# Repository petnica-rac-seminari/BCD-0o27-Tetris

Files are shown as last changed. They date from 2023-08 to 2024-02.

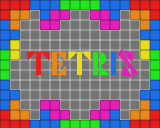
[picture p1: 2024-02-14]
firmware/framework/src/start_screen.png

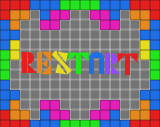
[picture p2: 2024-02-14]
firmware/framework/src/end_screen.png

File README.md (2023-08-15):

CHECK THE DOCUMENTATION FOLDER FOR INFORMATION ABOUT THE HARDWARE AND HOW TO BUILD IT.

The BalcCon Cyberdeck 0o27 (BCD-0o27) comes with a development framework that makes it easier to add functionality to the cyberdeck. This development guide introduces the framework, advises coding best practices and provides examples for adding functionality to the BCD.
Of course, you can ignore all of that and program the BCD either with esp-idf, rust, or any other framework that allows you to program ESP32 chips directly. However, this is not covered in this guideline.

# Introduction to the BCD-0o27 Framework
Before reading this chapter it is advisable to get  a local copy of the framework (see [[#Getting the Framework]]) and set up the development environment (see [[#Setting up the Development Toolchain]]). 
The framework consists of the following components:
- **Drivers**: The drivers for the hardware, namely the ST7735 display, the WS2812 LEDs  and the input buttons (aka controller) as well as the serial console. (Sometimes, drivers and libraries are not distinguished)
- **Libraries**: Libraries are provided for common tasks like opening a console on the serial port, establishing ssl connections or displaying graphical elements.
- **Modules**: Modules are programs that can be launched by the user. They can be simplest demo applications or complex programs.
- **Console Commands**: Console commands are programs that can be launched from the console. As modules, console commands can have any level of complexity. While usually they mainly interact with the serial console, they may - just as modules - access other hardware as well.

This document is currently being developed. For the time being, it is recommended to check the appendix to clone the repository. Then use the example firmware provided in the directory.

> [!info]
> You can connect to the badge using a serial console and a usb-c data cable. Make sure you use a terminal that understands ansi sequences. You can use the integrated serial monitor of platformio or espressif, but its highly recommended to use syncterm or minicom.

> [!warning]
> There currently is a bug in the serial console that will not give you a prompt when you connect using a serial terminal. In that case, leave the connection open and simply reset the badge by pushing the reset button - left button under the display.

# Appendix
## Getting the Framework
The framework is hosted as a git repository at https://gitlab.com/fschuetz/bcd-0o27.git. The repository makes heavy use of submodules, as many components for the BCD-0o27 are developed in parallel.
To create a local repository using git follow these steps:
```bash
git clone --recurse-submodules https://gitlab.com/fschuetz/bcd-0o27
```

## Setting up the Development Toolchain
In this chapter we will show how to set up the development environment consisting of git, espidf, Microsoft Visual Studio Code and Plattformio. If you are an experienced user, feel free to use the IDE of your choice.
### Installing GIT and cloning the repository
We will use git from the command line, as we have to deal with submodules, which are not well supported in the Visual Studio Code IDE.
If you have git already installed, you can skip this step.
1. Install git for your platform. Follow the guide at [Gitlab](https://docs.gitlab.com/ee/topics/git/how_to_install_git/)
2. Clone the repository: 
    ```bash
    git clone --recurse-submodules https://gitlab.com/fschuetz/bcd-0o27
    ```
Some tips on working with submodules, in case you run into a head detached situation: https://stackoverflow.com/questions/18770545/why-is-my-git-submodule-head-detached-from-master

### Install Microsoft Visual Studio Code (VSCode)
1. Install [VSCode](https://code.visualstudio.com/) for your operating system.
2. Open VSCode.

### Install C/C++ and PlatformIO Extensions
1. In VSCode: Open the "Extensions" side bar on the left side.
2. Search for the "C/C++" extension by Mircrosoft and install it.
3. Search for the PlatformIO IDE by PlatformIO and install it. See [PlatformIO IDE for VSCode](https://docs.platformio.org/en/latest/integration/ide/vscode.html#ide-vscode)
4. Once installation has finished, restart VSCode

### Build and Upload the Firmware 
In this chapter we will build the filesystem image and the firmware and upload both to the badge. If this works, then you can start developing your own firmware using the framework. For testing we highly recommend, taking the example in the directory `firmware/example` rather than the framework, as the example will give you running firmware that allows you to see something actually happening.
1. Start Microsoft Visual Studio and make sure you are in a new window, with no project loaded.
2. Select the alien head in the left bar (Platformio menu)
3. A left band appears. Select the blue button "Pick a folder"
4. From the cloned repository choose the `firmware/example` or the `firmware/framework` folder (as written above, its recommended to start with the example rather than the plain framework).
5. Click open.
6. Wait for platformio to configure itself. This is IMPORTANT: Between now and building the file there might raise popups in the bottom left corner asking you to install extensions or configurations. Usually you are asked to intall C++ specific extensions and CMake specific extensions. Confirm all of them. For CMake, if asked, you can "scan for kits". Scan for kits may also go away on itself, then everything is fine as well. 
7. If all went well so far you will recognise a blue ribbon / button on the bottom and some symbols like a home, a checkmark, roght pointing arrow etc.. If there is the message "Platformio: Loading tasks..." wait until it disapears. (this may take a long while). PlatformIO will automatically configure the project.
8. Open the file main.cpp in the "src" folder.
9. In the bottom task list (with the blue ribbon / button and the checkmark etc...), first choose the build environment by clicking on the symbol that looks like a folder and says "Switch Platformio Project Environment" if you hover over it. Usually it reads default right to the symbol. Choose `env:BCD-0o27-5KY` (or the `env:BCD-0o27-5KY-release` if you want to build for release rather than debug - if unsure make a debug build).
10. Now select the checkmark to build the project. This builds the project. Dependencies are pulled in automatically. In case Platformio does not pull in the Espressif 32 framework, follow the steps in the note below to install it manually.
11. If the project builds successfully, connect your badge to the computer using a usb-c cable (make sure it is actually a data cable and not just a charging cable)
12. Make sure the device is recognised. If the device is not recognised and a com port assigned, you might have to install a driver for the CH340 serial bridge. Follow the instructions from [Sparkfun](https://learn.sparkfun.com/tutorials/how-to-install-ch340-drivers/all#drivers-if-you-need-them)
13. Once the device is recognised, in VSCode we will build the file system image, upload it and then upload the code.
14. From the side bar choose the PlatformIO icon (alien head)
15. Select BCD-0o27 -> Plattform -> Build Filesystem Image
16. When finished, select BCD-0o27 -> Platform -> Upload Filesystem Image (BCD-0o27)
17. When finished, select the right pointing arrow ("Platformio: Upload") in the blue ribbon at the bottom. The project will be built and uploaded to the badge.
18. Either launch the serial console from the blue ribbon by selecting the plug icon ("Platformio: Serial Monitor") or use minicom (preferred). Note, that the Platformio Serial Monitor may display some strange characters or double print the prompt as it does not fully support the output mode. IMPORTANT: Due to a bug, the serial console only works for input if the connection was made at badge startup. If you do not see a prompt, leave the console on and restart the badge by pushing the power button (left between display and battery holder).
19. CRITICAL: Make sure, that you DO NOT have a serial monitor running when trying to flash the badge. This will lead to flash failure (for both, filesystem and firmware).

Note: The Espressif 32 framework should install automatically when building the project. If this is not the case, you can install it manually:
1. Open the Platformio sidebar (left side, alien head icon).
2. Select PIO Home -> Platforms
3. Click on the "Embedded" tab. Search for "Espressif 32" and click it.
4. Install the latest version. (At the time of writing this is version 5.1.0. While we plan to adapt the framework to newer versions, you might want to select this version if the newest version is not working due to breaking changes.)
5. Once the installation has completed confirm the success dialog.
### Helpful Resources
[Espressif 32 for Platformio](https://docs.platformio.org/en/latest/platforms/espressif32.html)

## Misc notes - ignore please
### Updating mirrors 
Go to lib directory of mirror
```
git fetch upstream 
git merge upstream/master
git push
```

### Updating submodules
```
git fetch
git pull
```

# Coding Style
```c++
ESP_LOGE(TAG_MODULE_NAME, "This is a rather long error message."
		"It should be spred on two lines");
```
If functions too long, spread on multiple lines. Two lines, indent second line by one tab and finish the line with closing bracket and ;. If more than two lines use one argument per line and close on a separate line as follows:
```c++
myfunction_with_many_arguments(
	argument 1,
	argument 2,
	argument 3

```

TO BE CONTINUED

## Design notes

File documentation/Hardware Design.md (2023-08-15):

Version: 0x00
Applies to: HW Rev. 0x00

This guide describes design considerations for the BCD-0o27. Note that not all of these were used in the actual design.

## Purpose of the document
This document describes the hardware design options and design decisions for
the BalcCon Cyberdeck BCD-0o27.

## General HW Design Considerations and Decisions
According to the [concept document](CONCEPT.md) the cyberdeck needs to support
the following functionality:

1. Some means of input to solve riddles / control programms stored on the badge
1. A display to display programm / riddle output
1. Storage to store programs and riddles on the badge
1. Some means to blink patterns on leds and some means to record blinking
    patterns from other badges
1. Run on battery power and alternatively be powered by USB. Optionally support
    charging of the battery over USB
1. Support wireless communication to connect to mutli user dungeon (mud)
1. Support a means to communicate with a computer using the badge to access the
    mud

### Core Module
The core modules ideally supports wireless communication WiFi and bluetooth out
of the box, offers a multitude of serial interfaces and has either built in 
flash storage or can easily be connected to external storage. Further, the core
module should be able to run code for passing through serial to WiFi for MUD
access as well as offer the mini games and riddle that run badge local. 
Considered options are:

1. Using an ESP32 as the core module.

    - ***Pro***: We know it well and it supports WiFi, Bluetooth and many
        serial communication protocols. Also the ESP32 offers many GPIO pins.
        The price for modules is low, sourcing is easy and there is a big 
        community for support.
    
    - ***Con***: ?

1. Using an STM32 as the core module.

    - ***Pro***: Low power CPU used in many projects.

    - ***Con***: Knowledge about the STM32 is small with the authors. Prices
        currently raise for this chip due to global shortage. Does not have 
        WiFi or bluetooth built in.

(***DECISION***) We will use the ESP32 as core module for the badge.

### Controls
The badge shall support a mode of direct input that allows navigating a menu
and playing little games / enter text or codes for applications running localy
on the badge. The options for input are:

1. Only push buttons. Due to space constraints, a full push button keyboard
    does not seem feasible. Therefore a layout of four push buttons to naviagte
    left / right / up / down makes sense. Further at least two push buttons,
    one for selecting an input and one for canceling / go back is needed. This
    layout would also allow for simple games such as pac man, snake or simple
    jump and runs.

    - ***Pro***: Requires only digital inputs, no analog to digital converter.
        The buttons can be arranged in a matrix which requires 5 digital input
        pins. Left / right / up / down can be all pressed at same time, which
        supports diagonal movement in games.
    
    - ***Con***: Limits controls in little games as movement if full or none.
        Pressing buttons for left / right / up / down can be a little fiddly in
        games. eft / right / up / down can be all pressed at same time, which
        needs to be checked if it makes sense (eg. up and down simultuously 
        often does not make sense.)

1. Similar to the configuration above, but instead of push buttons for left / 
    right / up / down use a digital mini joystick.

    - ***Pro***: More natural steering in games. Avoids the checks for 
        simultanious button presses as only one direction can be active at a
        time. Still requires only digital inputs and can be arranged in a 
        matrix (TODO - maybe even more optimized as simultanuous button presses
        can not happen).

    - ***Con***: Limits controls in games due to digital logic (full or none).
        Combinations that make sense might not be available as the joystick
        might not support eg. top + left combinations (TODO - check if there
        are digital versions that support this. Note: Also NES and old consoles
        did not support this, so it is possible to design around that.)

1. Have an analog mini joystick (potentially also including a button press if
    pushed) for movement in menus and games and add two (or potentially more)
    buttons for select and back.

    - ***Pro***: Natural movement in games using analog signals to capture
        intensity of the move. Only sensible inputs for navigation (no up and
        down simultaniously). 

    - ***Con***: Requires at least four analog pins hooked up to an analog to
        digital converter (ADC). ADC2 cannot be used on the ESP32 as we use
        WiFi. ADC1 can be used but might also be used for other functionality
        such as LDO and LED. Might require having a separate ADC circuit and
        using a serial protocol for input to save GPIOs on the ESP32.

(***TODO***) Choose option and derive requirements in the chapter below. 
Proposal is to go with the simplistic 8 button variant first and only maybe
later consider going to a more complex version. Simplicity allows us to use
directly 6 digital pins and reduces complexity of the circuit, cost and 
development time.

### Display output
TODO - describe different display options (size / technology)

### Balcon Badge Blinky Logic Circuit (B3LC)
The B3LC consists of two parts: A set of six photosensitive elements to measure
light and a set six light emitting diodes (LED) to emit light. We start with 
some considerations for the photosensitive elements.

The photosensitive elements need to capture the light of the LEDs of other
badges to decode the blinking patterns those have. There are some options on
the photosensitive elements to use:

1. Light dependent resistors (LDR) are resistors whose resistance drops with 
    the amount of light that falls on them. This allows to determine the 
    brightness of the light source. 

    - ***Pro***: Simplicity of the circuit, availability and low cost of parts.

    - ***Con***: Each LDR needs to connect to an anaolg pin which means either
        the LDRs exhaust all available PINs on the ESP32 (ADC1, as AD" canot be
        used when using WiFi) or the LDRs need to be hooked up using an ADC
        multiplexer (ADC-MUX) which increases design complexity (but on the 
        other hand allows us to use a more exact ADC than the one of the ESP).

        Stray light is an issue with the LDRs as it influences the read values.
        This must be designed around by either developing a robust decoding 
        protocol with coarse granularity and fault tolerance and / or design
        the BCD-0o27 with some casing elements to snug fit LED on LDR when two
        badges are combined. 

1. Using a digital red, green and blue color light sensor (like for example the
    ISL29125) allows to directly detect light and its colors and decode it in a
    digital format.

    - ***Pro*** Allows to use a bus to communicate with the sensor and directly
        use digital pins. There are sensors with infrared blocking filter which
        reduces the amount of error. Also, detecting rgb components of light 
        allows for using more complex blinking patterns and introducing better
        error correction.

    - ***Con*** Cost of parts. Sourcing of parts. Also depending on what bus the
        parts use to communicate with the ESP32 more or less pins are used. If
        the part uses I2C it needs to be ensured that 6 different addresses are
        available and no adress collisions with other parts (eg. maybe display)
        occure. Parts using I2S buses do not suffer from these conditions but
        use more pins for chip select.

The LEDs need to emit light in a pattern such that it can be captured by the 
photosensitive elements and decoded. For this the following options exist:

1. Use a single colour (potnetially different ones for each) LED that either is 
    off or on.

    - ***Pro***: Easy to source (also as SMD), low cost, low complexity. Can be
        directly connected to 6 digital output pins of the ESP32. Keeps the 
        circuit complexity low and does not need additional parts.

    - ***Con***: Does only allow simplistic light patterns. Also limits the
        complexity of patterns that can be recognised as codes can only use
        on / off state and complexity of patterns must be introduced by using
        longer codes (not necesserily a bad thing). Maybe some poor peoples PWM
        to have different brightness levels could be implemented in software to
        allow for interesting patterns (using interrupts for exact timing)?

1. Use single colour LEDs but steer them with pulse width modulation (PWM) to
    allow for different brightness.

    - ***Pro***: Allows for more complex protocols having multiple states 
        depending on LED brightness (limited by accuracy of decoding). More
        important, allows for more interesting light patterns (pulsating lights
        and so on). The ESP32 supports 16 pwm channels grouped in two 8 channel
        groups.

    - ***Con***: None pwm specific. (?)

1. Use rgb tri-color LED steered with pwm.

    - ***Pro***: Allows for very interesting LED effects and also allows to
        come up with a sophisticated light coding protocol.

    - ***Con***: Litle more expensive than single color leds, little increased
        power consumption. Needs either a bus to steer leds or 18 channels.
        This exhausts the 16 available pwm channels on the ESP32 and also its
        not sure if enough pins are available (TODO - revisit after deciding on
        other peripherals) to have eg. 16 pwm channels and 2 digital.

(***TODO***) Add more options (maybe) and decide on what option to implement
first. While RGB LED with RGB light sensor is most interesting, it is also the
most complex and could be reserved for future badges. Maybe go with simple LDR
and pwm controlled leds (single to start, then maybe RGB as for LDR only 
intensity, not colour matters).

### Variants
On the one hand, device cost will be crucial for the BCD-0o27. On the other the
plan is that the BCD-0o27 can be used for several years to come (even if there
might be new version, we strive for backwards compatability). This means some
more robust and thus more expensive design choices might be justified (for 
example the USB port could be protected against ESD or USB Power Delivery 2.0
could be implemented to ensure the USB port where the BCD-0o27 is connected can
source enough power instead of just not functioning porperly when connected).

Depending on the time available, we might offer multiple variants of the 
BCD-0o27 at different price points:

- IFL variant: The "I feel lucky" variant will be designed with minimum safety
  and cheapest possible parts.

- TRD variant: "The real deal" variant will implement bells and whistles and
  use quality, but more expensive chips for some functionality.

## Core Module Design

### Requirements
- (REQ-COR-001) Run programms and mini games
- (REQ-COR-002) Establish and maintain connection to mud
- (REQ-COR-003) Redirect input from serial line to mud
- (REQ-COR-004) Redirect output from mud to serial line
- ...

### MMU
At the heart of the BCD-0o27 an ESP32 will be used. The ESP32 is a highly 
integrated MCU that offers WiFi and Bluetooth functionality. At its core is a
Xtensa 32 bit microprocessor (single and dual core available). It has rom and
sram memory and supports various clocks and timers. The ESP32 offers advanced
interfaces to serials through 34 programmable general purpose input and output 
pins (GPIOs). It supports SPI, I2S, I2C and UART interfaces. It also offers low
power sleep modes which makes it a good choice to run on battery power. Further
it has  some security mechanisms such as secure boot, flash encryption and 
hardware  acceleration for some common algortihms. Last but not least the ESP32
features a mature development environment, comes with a large community that
supports developers and can be acquired cheaply. A complete overview about the
ESP32 can be found in the [ESP32 Series Datasheet](https://www.espressif.com/sites/default/files/documentation/esp32_datasheet_en.pdf)

(***NOTE***) The final decision on what ESP32 module to use exactly still needs
to be taken. Experiments will be conducted currently with a ESP32-WROOM-32E 
module and / or ESP32 DEVKIT (which includes USB power and serial interface). 
All the Pinouts given in this document refer to the ESP32-WROOM module. Refere 
to the [ESP32-WROOM-32E datasheet](https://www.espressif.com/sites/default/files/documentation/esp32-wroom-32e_esp32-wroom-32ue_datasheet_en.pdf)
for further information.

The WROOM32 has the following pinout (***WARNING*** physical pin numbers in the
image do not match the datasheet. We use the pin numbers from the datasheet.
Those start with pin 1 in in the top left corner and then increment by one
counterclockwise).

ESP32 WROOM32 pinout ESP32-WROOM32 pinout

### Power Management
The ESP32-WROOM needs the following pins to be connected for power:

| Pin | Name | Function |
| :---: | ---- | --- |
| 1 | GND  | Ground |
| 2 | 3V3  | 3.3V power supply (2.3V ∼ 3.6V, min 500mA) |
| 3 | EN | Module enable signal (active high) |

The power provided to the module must be within 2.3V and 3.6V. The EN pin can
be used to deactivate the module completely. However, the design of the 
BCD-0o27 does not foresee this. To preserve power, the ESP32 will be put into
deep sleep, but always be active. Therefore the EN pin will also be connected
to the 3.3V rail of the power supply. To ensure the power supply to the ESP32 
chip during power-up, it is advised to add an RC delay circuit at the EN pin.
The recommended setting for the RC delay circuit is usually R = 10kΩ and 
C = 1µF. 

(***DECISION***) The EN pin will be connected to a switch that is connected to
ground. This switch then operates as a reset switch to reset the ESP32.

(***DECISION***) An RC delay circuit with R = 10kΩ and C = 1µF will be added at
the EN pin.  

RC Delay Circuit

(***DECISION***) A 0.1µF and a 22µF capacitor in parallel will be added close 
to the 3V3 pin to filter ripples in the power supply rail.

### GPIO
The ESP32 features 34 GPIOs. Each GPIO has a mximum current draw rating of 
40mV. Due to the usage of the internal flash memory and the wireless some GPIOs
will not be available. The following GPIOs are reserved and canot be used:

| PIN  | GPIO | Reserved for |
| ---: | ---: | --- |
| 17 |  9 | Connected to integrated SPI flash |
| 18 | 10 | Connected to integrated SPI flash |
| 19 | 11 | Connected to integrated SPI flash |
| 20 |  6 | Connected to integrated SPI flash |
| 21 |  7 | Connected to integrated SPI flash |
| 22 |  8 | Connected to integrated SPI flash |

The remaining GPIOs listed in the table below are available for use in the 
BCD-0o27. However, the use of some requires to take special care as they fulfil
important functions:

| PIN  | GPIO | Type  | Limitation | Used for | 
| ---: | ---: | :---: | --- | --- |
| 13 | I / O | - | unused |
| 23 |  15  | I / O | Strapping pin, pwm at boot | SPI Bus Chip Select (Display) |
| 24 | 2  | I / O | Strapping pin | SPI Bus Data Command (Display) |
| 25 | 0  | I / O | Strapping pin | unused |
| 26 | 4  | I / O | - | SPI Bus Reset (Display) |
| 27 |  16  | I / O | - | unused |
| 28 |  17  | I / O | - | unused |
| 29 | 5  | I / O | Strapping pin, pwm at boot | unused |
| 30 |  18  | I / O | - | SPI Bus Clock (Display) |
| 31 |  19  | I / O | - | SPI Bus MISO (None) |
| 33 |  21  | I / O | - | Add on connector (I2C) Interface (SDA) |
| 34 | 3  | I / O | RX, high at boot | unused |
| 35 | 1  | I / O | TX, debug output at boot | unused |
| 36 |  22  | I / O | - | Add on connector (I2C) Interface (SCL) |
| 37 |  23  | I / O | - | SPI Bus MOSI (Display) |

***Strapping pins*** are sampled during the sample the voltage level during the
chip's system reset relase (power-on-reset, brown out reset, watchdog reset) as
strapping bits of "0" and "1". Those strapping bits determine the devices boot
mode, the operating volatage of VDD_SDIO and other system settings. See 
chapter [Boot Up](#boot-up).

### Boot Up
In order to boot the ESP32 up correctly the strapping pins must be set as
follows:

| Strapping PIN | Set | Effect | Mapping WR32E |
| --- | --- | --- | --- |
| MTDI |  0  | Set voltage to 3.3V | IO12 / pin 14 |
| GPIO0 | 1/0 | 1 on normal boot, 0 to flash new code | IO0  / pin 25 |
| GPIO2 | ?/0 | Must be 0 when flashing, don't care otherwise | IO2  / pin 24 |
| MTD0 |  0  | Debug output for boot (set 1 for development) | IO15 / pin 23 |
| GPIO5 |  1  | Rising edge sampling and output | IO5  / pin 29 |

Note that the strapping pins must be set during the system reset release (boot
phase) of the chip. The system reset release can be triggered by three 
conditions:
1. Startup of the chip, power on reset (EN pin goes high and system is powered)
2. RTC watchdog reset (TODO - excat conditions? Every wakeup?)
3. Brownout reset (voltage was too low or unstable to continue operation)

After system reset release (when the ESP32 enters normal operation) the pins 
are no longer relevant can be used as regular gpios.

It follows an explanation on the choice made above:
- MTDI: MUST always be set to 0, as the module only operates on 3.3V.
- GPIO0: In normal operation must be set to 1 to boot normally. When flashing
    new code on the chip must be set to 0.

    ***OPEN DECISION***: Shall we allow flashing new code after development?
    
        Pro: Could release new updates to the batch easily. Also we could either
        design it in a way where it is easily trigerable (using a switch) 
        encouraging tinkering with the badge or we could make it more difficult by
        bringing out a trace that can then be hooked up to a flasher that pulls the
        pin low making this more difficult, disencouraging fundamentally changing
        the badge.

        Con: Reflashing something completely new could render the badge to be
        used in ways not foreseen and make devleoping a interesting game 
        experience more difficult (more fault cases). In this case the HW 
        design must be such that it is really difficult to set the pin to low 
        at bootup.

        Decision: TODO

- GPIO2: When flashing (GPIO0 set to 0) must be set to 0. Otherwise does not
    matter. 

    ***OPEN DECISION***: Set to 0 during boot to be on the safe side when 
        reflashing or don't care?

        Pro: Setting to 0 at boot rules out one source of failure for flashing
        new code.

        Con: Depending on what is connected to the GPIO2 it could make the 
        circuit and software design more difficult to ensure that after boot
        the value needed by the connected chip or device is there.

        Decision: TODO

- MTD0: Sets whether debug output is given (on TXD0 / GPIO 1, which is pin 35
    on the ESP32-WROOM32E module). Can be set to 1 for development but is 
    disencouraged for use in release. Therefore must be set to 0 in release.

- GPIO5: If MTD0 is set to 0 does not matter. However, if MTD1 is set to 1 this
    pin defines the timing of the SDIO slave together with MTD0. TODO - decide
    what to use. Currently chosen 1 randomly.

### Entering Flash Mode
If we decide to allow for easy flashing, we will design two ways to flahs the
ESP32: Auto (if flasher supports it) and manual by button press. When using a
flasher (like [esptool.py](https://github.com/espressif/esptool) for example), 
some flashers will use DTR and RTS to signal that they want to flash. Thus 
those can drive transistors to switch the boot mode. Also, as some tools do not
support this a button to be manually pressed will be added. This button needs 
to be debounced using a capacitor.

## Blinky Interface
TODO

## Display
TODO

## Controls
The BCD-0o27 will feature a set of inputs:

For the joystick we will use a simple analogue 

### Circuit Design
We design the input of the buttons using a shift register. This allows to
record multiple buttons presses while only needing two pins on the ESP32
(serial in and clock).

### D-Pad Design
TODO

### Button Design
TODO

## Serial Interface
TODO

## (OPIONAL) Debug Interface
TODO

## Power Supply
(***WARNING***) Currently this chapter is very rough as components are not yet
decided. It must be adapted during the process. It is important to do this as
changing power requirements can rule out some options. We likely aim to high at
the moment, but this is preferable to too low.

The BCD-0o27 must be mainly powered by batteries to allow it to operate on its
own. When hooked up to an alternate power source this source shall be used to 
power the badge. Charging the battery is optional. 

### Requirements
The power supply design for the BCD-0o27 must fulfil the following 
requirements:
- (REQ-POW-001) Provide enough output current to power the BCD-0o27. For the
    exact amount check calculation in 
- (REQ-POW-002) Provide a 3.3V rail (min. 2.3V / max. 3.3V - may change 
    depending on additional parts used as they might have different power 
    requirements)
- (REQ-POW-003) Switch from battery power to external power source if attached
- (REQ-POW-004) Batteries shall be easy to source and replace
- (REQ-POW-005) Less hazardous battery technology shall be prefered
- (REQ-POW-006) Protect from reverse polarity

### Output current
The minimal amount of current the power supply must deliver is estimated by 
the sum of the current need of all components at typical full operation (ie.
for ESP32 this means wireless enabled and computing) and then add 10% as safety
margin.

NOTE: This current estimate is subject to change due to component selection
for the not yet selected components. Update accordingly.

    ESP32            500 mA (1)
    6xLED            360 mA (2)
    LCD               60 mA (3)
    3xShift reg.       3 mA (4)
    ----------------------- 
    Total            923 mA  

    (1) Typical operating current. Cummulative IO output current is 1200 mA.
    (2) If using WS
    (3) Measured ILI operated at 3.3V
    (4) To be confirmed

### Battery Options
The following options are considered for the BCD-0o27: 
- NiMH AA batteries
- Alkaline AA batteries
- LiFePo AA batteries
- LiFePo 18650 batteries
- Li-Ion 18650 batteries
- Li-Ion accu 3.7V (single cell)

The following table summarises properties of the different battery types. Note 
that depending on the manufacturer these values might differ slightly, however
this will not affect the design.

| Battery | Voltage nom/max/min | Capacity mAh | Max. discharge |
| --- | :---: | ---: | ---: |
| NiMH AA | 1.2 / 1.5 / 1.2 |  600–2750 | 3C |
| Alkaline | 1.5 / 1.5 / 1.2 | 1800–2850 | 0.5A - 0.75A |
| LiFePo AA | 3.2 / 3.65 / 2.0 | 600 | 3C (1800mA) |
| LiFePo 18650 | 3.2 / 3.65 / 2.0 | 1400 | 3C (4500mA) |
| Li-Ion 18650 | 3.6 / 4.2 / 2.5 | 2500 | 8C (20A) |
| LiPo pack 1S | 3.7 / 4.2 / 2.75 | 2000 | 1C (2000mA) | 

#### NiMH and Alkaline AA Batteries
NiMH and alkaline AA batteries have the big advantage that they can be found
anywhere and their price is low. Alkaline batteries however only provide a
continuous discharge current of 0.5A - 0.75A. While this should be enough for
regular operation, it does not provide many reserves and alkaline batteries in
general operate better at low discharge currents. 

Both, NiMH and alkaline AA batteries can directly supply enough voltage for 
the ESP32 without any voltage conversion. This reduces the complexity of the 
power supply design. The same should go for the OLED display, however, this 
must be verified (TODO). The charging circuit for rechargeable NiMH AA 
batteries is a little more complex, as two cells should be balanced to allow 
them both to fully charge. Also, if charging starts automatically when plugged
in to an alternate power supply, it might be that non rechargeable batteries 
are in use and the cahrging circuit canot detect this. Therefore the easiest 
design choice would be to not implement a chargin circuit and let the user 
change batteries when running low on power.

| Pro | Con |
| --- | --- |
| Battery safety | Charging circuit |
| Easy sourcing | Voltage below 3.3V (3V - 2.4V) |
| Low cost | Alkaline: low current < 750mA  |
| No need for buck / boost converter | |

TODO - charging circuit design (OPTIONAL) 

#### LiPo Pack 1S
A single cell LiPo battery pack has the advantage that a charging circuit is 
not too complex as no cell balancing is needed. The single cell LiPo battery
also is rather small and will only slightly increase badge volume and weight.
It offers decent capacity and enough continuous discharge current. 

Safety is a concern with LiPo batteries as over charging them may lead to fire
and over discharging them will permanently damage the battery. A wide range of 
ready made ICs for battery management exist and usually only require a couple 
capacitors and resistors asides the IC itself. Those battery management ICs are
needed for charging and discharging. They will take care of over charge and 
over discharge protection.

As a fully charged LiPo has a voltage of 4.2 V, this must be stepped down to
not damage the 3.3V logic components. The LiPo battery can be discharged to
2.5V although not discharging below 3V is recommended for battery longlifety.
Also, the residual usable charge between 2.5V and 3.3V is around 3% of the 
total usable charge. In order to provide power to the ESP32 and the other
components a 3.3V low dropout regulator (LDO) could be used. However, this 
would not allow us to use the full capacity range. Another option would be to
use a LDO that outputs 3V or even 2.5V, which would be enough for the ESP32. 
However, as with NiMH AA batteries this would need to be verified for the 
display and the other components. Alternatively a buck-boost converter could be
used to use the full range while providing a stable 3.3V power rail. The buck-
boost converter on the other hand generates an electromagnetic field that could
influence wireless quality if placed to closs to the ESP32. 

| Pro | Con |
| --- | --- |
| Can provide stable 3.3V power rail | Battery safety |
| Low cost | Needs battery management |
| High current (1C) | Sourcing need lead time |
| Reasonably simple charging circuit | |
| Low weight and volume | |

(***DECISION***) Even though many LiPo batteries come with a built in 
protection circuit, we will still design the protection circuit in the
BCD-0o27 to prevent bad things from happening if someone uses a battery
without a protection circuit.

#### Li-Ion 18650 battery
For the LiPo 18650 battery the same applies as for the Li-Ion pack 1S with the 
only difference that the battery uses more volume but provides roughly 25% more
charge and supports a higher average discharge current. 

| Pro | Con |
| --- | --- |
| Can provide stable 3.3V power rail | Battery safety |
| Low cost | Needs battery management |
| High current (8C) | Sourcing need lead time |
| Reasonably simple charging circuit | Larger volume |
| Low weight | |

For charging a single cell Li-Ion battery the 
[TP4056](https://download.bastelgarage.ch/Datasheet/TP4056_Datasheet.pdf) 
standalone linear Li-Ion battery charger with termal regulation in SOP-8 
package is frequently used. It charges the battery with a maximum of 1A 
directly from the USB port (5V supply) but can also be used with 6V solar 
panels. The chip features over voltage protection. It charges the battery to 
4.2V.

For protecting the the battery from over discharge, a 
[DW01](https://download.bastelgarage.ch/Datasheet/DW01A_Datasheet.pdf) in 
combination with a 8205 dual mosfet can be used.

(***DECISION***) If we decide to use multiple Li-Ion 18650 batteries in 
parallel to increase total capacity we will add fuses between the cells
to prevent fire hazard due to over discharge induced by a defective Li-Ion 
cell (short cell). The fuse disconnects the faulty cell.

#### LiFePo 18650
The main advantages of LiFePo over LiPo are that they are safer to use as they
will not burst in fire if overcharged and they also have a maximum voltage of
3.65V which is just at the top limit of the ESP32. Therefore no LDO or buck-
boost converter is needed.

TODO - check charge circuit and low power cut off necessity.

#### LiFePo AA
TODO

### USB Power
The BCD-0o27 will support powering from the USB-C port (see 
[AN1953 Introduction to USB Type-C](https://ww1.microchip.com/downloads/en/appnotes/00001953a.pdf))
for a good overview). Therefore the port on the BCD-0o27 is configured as an 
upstream facing port (UFP) and using pull down resistors on CC1 and CC2 to 
announce supported power requirements. We will only support 5V power modes. To
indicate voltage and max current, a Rp pull-down resistor must be used on both
CC1 and CC1. As the USB Type-C shall support charging at 1.5A@5V (at minimum) a
5.1kΩ±10% must be used. (Note: This results in a voltage divider when a cable
is attached. Depending on the resistor Ra used in the downstream facing port
The supported power mode is indicated. O

***Note***: The downstream facing port decides on the power capability it has
to offer. The minimum is 500mA / 900mA (USB2 standard). If the BCD-0o27 needs
more than 500mA we might run in problems when attached to a host that only
supplies 500mA. To avoid this we should implement the power delivery protocol
to indicate a minimal current requirement. However, we might also just ignore
this for simplicity and tell users. To be decided once total power requirements
are known.  

When plugged in the USB power shall be used to power the badge to safe battery
power. If we decide to use LiPo or LiFePo4 batteries, a charging circuit must
also be powered from the USB port. If we decide upon NiMH batteries charging
will not be supported as we want to avoid users using non-rechargeable 
batteries that are then charged inside the device. As chargers are cheap and
everyone has them this is an acceptable design choice that also reduces 
complexity and cost.

Last but not least, we might add ESD protection. ESD protection vill prevent
spikes due to ESD induced by humans plugging in the USB cable. Basically we
have two options:

1. [USBLC2-S2C6](https://datasheet.lcsc.com/lcsc/2106070106_UMW-Youtai-Semiconductor-Co---Ltd--USBLC6-2SC6_C2687116.pdf) 
   is designed for USB 2 applications. As we use a USB Type C plug
   with USB 2 protocoll, this is a feasible solution.

2. [TPD4E02B04](https://datasheet.lcsc.com/lcsc/1809131529_Texas-Instruments-TPD4E02B04DQAR_C106794.pdf) 
   is a 4-Channel ESD Protection Diode for USB Type-C and HDMI 2.0
   and is compatible to USB 3.1 GEN2, should we want to use those features.
   (unclear, but might even be needed if we want to use power delivery (TBC))

***Decision***: For the moment we will go with the USBLC2-S2C6 as we only use
   USB 2.0 features.

### Power Rails
The operation of the ESP32 requires a 3.3V power rail. Further, the BCD-0o27
will be designed around 3.3V as much as possible to avoid needing another
power rail and therefore limit the use of DC-DC converters (drives down cost
and reduces wasted power).
TODO - 5V?

#### 3.3V Power Rail
Multiple options, depending on the used power source exist. In order to output
3.3V either a low dropout regulator (ldo), a switching buck converter / 
buck-boost converter can be used. 

Low dropout regulators are easy to use, but they have worse efficiency than 
switching dc-dc converters. Also they limit battery choices as the voltage
of the battery that can be used must be higher than 3.3V+Vdo (droput voltage).
On the upside, ldos do not generate electromagnetic waves and thus do not 
interfere with WiFi, bluetooth and other sensitive components.

Switching dc-dc converters on the other side

### Reverse Polarity Proteciton
The battery could be inserted in the wrong way (not the USB) and therefore the 
power path from the battery must be protected agains reverse polarity. This can
be done with a P-channel mosfet with the gate clamped to ground. Using a mosfet
has the advantage over using a diode that it wastes less power. A diode 
wastes forward voltage times the current (Vf * I) power. A possible mosfet is 
[AO3401A](https://www.lcsc.com/product-detail/MOSFETs_BORN-AO3401A_C306862.html)
Note that the AO3401A requires a minimum of 2.5V for its operation. But this 
is fine as we can live with cutting of at that value independent of the
battery and boost converter we use. The maximum gate threshold voltage for the
AO3401A is -1.3V. The minimal battery voltage as stated above will be 2.5V. 
The parasitic body diode of the AO3401A has a forward voltage Vf_max of 1.0V.
Thus the gate-source voltage Vgs is at least 0V - (2.5V - 1V) = -1.5V which
is larger than the required -1.3V threshold voltage and thus the mosfet will
turn on. Once the mosfet has turned on, the resistance between drain and
source will drop to max 85mOhm.

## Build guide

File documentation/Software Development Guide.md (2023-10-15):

The BalCCon Cyberdeck 0o27 (BCD-0o27) comes with a development framework that makes it easier to add functionality to the cyberdeck. This development guide introduces the framework, advises coding best practices and provides examples for adding functionality to the BCD.
Of course, you can ignore all of that and program the BCD either with esp-idf, rust, or any other framework that allows you to program ESP32 chips directly. However, this is not covered in this guideline.

# Introduction to the BCD-0o27 Framework
Before reading this chapter it is advisable to get  a local copy of the framework (see [Getting the Framework](#Getting%20the%20Framework) and set up the development environment (see [Setting up the Development Toolchain](#Setting%20up%20the%20Development%20Toolchain)). 
The framework consists of the following components:
- **Drivers**: The drivers for the hardware, namely the ST7735 display, the WS2812 LEDs  and the input buttons (aka controller) as well as the serial console. (Sometimes, drivers and libraries are not distinguished)
- **Libraries / Components**: Libraries and components are provided for common tasks like opening a console on the serial port, establishing ssl connections or displaying graphical elements.
- **Modules**: Modules are programs that can be launched by the user. They can be simplest demo applications or complex programs.
- **Console Commands**: Console commands are programs that can be launched from the console. As modules, console commands can have any level of complexity. While usually they mainly interact with the serial console, they may - just as modules - access other hardware as well.

We distinguish two kinds of development work: Firmware development and framework development. Firmware development is using the framework to develop your own firmware to run on the hardware. Framework development modifying the framework itself to improve its performance or utility. Of course, the separation is not strict, as developing custom firmware might require modifications at the framework. For the sake of this guide we will differ between the two as clean cut as possible.

This document is currently being developed. For the time being, it is recommended to check the appendix to clone the repository. Then use the example firmware provided in the directory.

> [!info]
> You can connect to the badge using a serial console and a usb-c data cable. Make sure you use a terminal that understands ansi sequences. You can use the integrated serial monitor of platformio or espressif, but its highly recommended to use syncterm or minicom.

> [!bug]
> There currently is a bug in the serial console that will not give you a prompt when you connect using a serial terminal. In that case, leave the connection open and simply reset the badge by pushing the reset button - left button under the display.

# Firmware Development
This chapter will explain the code structure for developing firmware. Driver and library interfaces / usage is described in chapter [Drivers and Libraries](#Drivers%20and%20Libraries). To develop firmware using the provided framework, you will likely add custom modules and / or console commands. You can either start out with a clean slate by cloning the pure framework or you can start modifying the example firmware. Both can be found in the [gitlab repository](https://gitlab.com/fschuetz/bcd-0o27) Details on how to set up the repository and development environment can be found in the [Appendix](#Appendix).
If you are eager to get your hands dirty, then feel free to jump right into the example subsection of the according section about modules or commands. The example section will be an easy to follow mini tutorial. Just make sure to revisit the whole section, as the example will not cover everything and not explain why things are done.
## Modules
Modules are "self contained" pieces of code that are usually started through the menu (or execute on their own without user interaction). Modules should be structured as follows:
```
mod_<name of module>/
       |
       |--> include/
       |        |
       |        |--> mod_<name of module>.hpp
       |        |--> ...
       |
       |--> src/
       |     |
       |     |--> mod_<name of module>.cpp
       |     |--> ...
       |
       |--> CMakeLists.txt
       |--> KConfig
```
Modules must be stored in the `/modules` directory of the framework. They usually reside in their own git repository and are added to the `/modules` directory as a submodule. 
You could clone the framework from the original repository and then just add a directory for your module (and would then not need the CMakeLists.txt and the KConfig). However, this makes it hard to share your module with others. 
### Include Directory
The include directory must at least contain the header file for your module. It should be named the same as you top level directory with the file extension .hpp (as you are likely writing a c++ module. If not, you can do it, but you there are certain things to respect on how to use a c module within.). If your module needs other header files, this is also the right place to put them if they are needed outside your module. If not you can put them wherever you want.

### CMakeLists.txt
The `CMakeLists.txt` file is important for compilation. It will enable your module to be found. The file template looks as follows:
```
idf_component_register( SRC_DIRS     "./src"
						INCLUDE_DIRS "./include")
```
This will tell the build system to register your component (under the name of the top level directory) and to find the include files in the `include` directory and the source files in the `src` directory. 
If your module depends on other modules, then you need to make this explicit in the `CMakeLists.txt` file. For example, if your module uses GFX (which requires the module gfx for the library and ch405labs_gfx_drivers for the graphics driver) to draw graphics on the screen, you need to modify the `CMakeLists.txt` as follows:
```
idf_component_register( SRC_DIRS "./src"
						INCLUDE_DIRS "./include"
						REQUIRES ch405labs_gfx_drivers gfx)
```
### Using Framework Components (Drivers / Libraries)
The framework already provides you some special modules (called components) that make it easier for you to develop your own things. See chapter [Drivers and Libraries](#Drivers%20and%20Libraries) on how to include them into your project.
### Example
In this chapter we will write a little example module from scratch to demonstrate the workflow. All paths used in this example are relative to the home directory. Adapt them to whatever structures you choose. The example as it is presented can be directly applied on a linux or mac computer using a shell of your choice. On windows, some adjustments of eg. path names may be needed.
Further, this chapter assumes that you have set up the development toolchain properly. If you haven't done so, consult If you have not yet set up Visual Studio Code see [Setting up the Development Toolchain](#Setting%20up%20the%20Development%20Toolchain) to set up your development environment first!

#### Preparation
First, we clone the framework (if you haven't done so already). Make sure to also clone the submodules:
```bash
git clone --recurse-submodules https://gitlab.com/fschuetz/bcd-0o27.git
```
Now it is time to set up an empty git repository of your choice ([github](github.com), [gitlab](gitlab.com) or any other you like). Choose `mod_example` as the name for your module. You can initialise the module with a `README.md` if you want.
When done, clone it as a submodule into the `/modules` directory of the framework. Make sure to use the path to your git repository and make sure to clone it such that you can push your changes back to the repository.
```bash
cd bcd-0o27/firmware/framework/modules/
git submodule add -b main git@gitlab.com:BCD_0o27/modules/mod_example.git
```
To write a new module, it is easiest to copy the template module from the repository. The framework has the template module already present in the modules directory. Lets copy the relevant files into our own module and rename the `.cpp` and the `.hpp` file.
```bash
cp mod_template/CMakeLists.txt mod_example
cp mod_template/Kconfig mod_example
cp mod_template/README.md mod_example
cp mod_template/LICENSE mod_example
cp -r mod_template/include mod_example
cp -r mod_template/src mod_example
mv mod_example/include/mod_template.hpp mod_example/include/mod_example.hpp
mv mod_example/src/mod_template.cpp mod_example/src/mod_example.cpp
```
We now need to adapt the template to fit our module name. For this, open a new window (`File -> New Window`)in Visual Studio Code. Then open the directory `bcd-0o27/firmware/framework/`. Allow some time for platformio to properly initialise. 
Next we need to adapt some defines, variables and other elements to reflect the name of our module. We start with the `Kconfig` file. In Visual Studio Code open the `Kconfig` file in the folder `modules/Kconfig`. Then find and replace all `MOD_TEMPLATE` with `MOD_EXAMPLE`.  Also replace the name `Template`in the statement `menu "Console Command: Template"` with `Example`. Alternatively you can issue the following command from the command line in the `modules/mod_example` directory:
```bash
sed -i '' -e 's/MOD_TEMPLATE/MOD_EXAMPLE/g' Kconfig
sed -i '' -e 's/Template/Example/g' Kconfig
```
Feel free to adapt or remove the comments in the file (marked by `#` as the first character or the line).
Your Kconfig should now look something like this:
```Kconfig
menu "Module: Example"
	config TAG_MOD_EXAMPLE
	string "Tag for logging"
	default "MOD_EXAMPLE"
	help
		The tag to use for log messages.
	
	choice MOD_EXAMPLE_LOG_LEVEL
            bool "Log level for Example module"
            default MOD_EXAMPLE_LOG_EQUALS_DEFAULT

            config MOD_EXAMPLE_LOG_EQUALS_DEFAULT
                bool "Same as default"
            config MOD_EXAMPLE_LOG_LEVEL_NONE
                bool "No output"
            config MOD_EXAMPLE_LOG_LEVEL_ERROR
                bool "Error"
                depends on LOG_MAXIMUM_LEVEL >= 1
            config MOD_EXAMPLE_LOG_LEVEL_WARN
                bool "Warning"
                depends on LOG_MAXIMUM_LEVEL >= 2
            config MOD_EXAMPLE_LOG_LEVEL_INFO
                bool "Info"
                depends on LOG_MAXIMUM_LEVEL >= 3
		config MOD_EXAMPLE_LOG_LEVEL_DEBUG
                bool "Debug"
                depends on LOG_MAXIMUM_LEVEL >= 4
            config MOD_EXAMPLE_LOG_LEVEL_VERBOSE
                bool "Verbose"
                depends on LOG_MAXIMUM_LEVEL = 5
        endchoice

        config MOD_EXAMPLE_LOG_LEVEL
            int
            default LOG_DEFAULT_LEVEL if MOD_EXAMPLE_LOG_EQUALS_DEFAULT
            default 0 if MOD_EXAMPLE_LOG_LEVEL_NONE
            default 1 if MOD_EXAMPLE_LOG_LEVEL_ERROR
            default 2 if MOD_EXAMPLE_LOG_LEVEL_WARN
            default 3 if MOD_EXAMPLE_LOG_LEVEL_INFO
            default 4 if MOD_EXAMPLE_LOG_LEVEL_DEBUG
            default 5 if MOD_EXAMPLE_LOG_LEVEL_VERBOSE
    endmenu
```
Now replace all the `MOD_TEMPLATE` and `mod_template` in `include/mod_example.hpp`. You can do this in the editor or from the command line. Make sure to keep the case, it matters:
```bash
sed -i '' -e 's/mod_template/mod_example/g' include/mod_example.hpp
sed -i '' -e 's/MOD_TEMPLATE/MOD_EXAMPLE/g' include/mod_example.hpp
```
Now we are going to edit the mod_example include file to prepare it for writing our program. Open up the file in Visual Studio Code and do the following:
1. Adjust the information about your module and you the author in the first comment block
   - @author: Your name an email where ppl can reach you for questions.
   - @brief: A brief description of your module, eg. `Example file for BalCCon Cyberdeck modules.` 
   - @version: 0.1
   - @date: The current date
   - @copyright: `Copyright (c) <year>, <your name>, released under MIT license` (or choose another license that suits your purpose better).
   - Replace the longer paragraph describing the module with a suitable description, eg: `This module display a hello world text on the display and blinks the led's. The module will terminate, whenever the user presses a button.` 
2. You can either choose to keep both, `#pragma once`and the include guard `#ifndef BCD_MOD_EXAMPLE_HPP ...` or you can choose one of them. If you are unsure, just leave them untouched and use google to see why this is bad or why it is good and why one is better than the other - or not. Depending on the community.
3. We do currently not need to change our includes, as we intend to use all of those. Of course, if for example you future module does not need the controller, you can remove the controller include (and adapt the CMakeLists.txt to remove this dependency).
4. For the sake of trying to keep coding style consistent, make sure the comments after `#define MOD_EXAMPLE_FAIL ...` and `#define MOD_EXAMPLE_OK ...` start at character 81 (you need to move them one character back by adding a space in front).
5. In the comment of the Main function, adapt the description. Eg. to `This is the entry point into our module. It will run a loop that blinks the leds and aborts if a button is pressed long enough`.
This is all the adaption we need to do at the current stage. Your `mod_example.hpp` should now look similar to this:
```cpp
/**
 * @file mod_example.hpp
 * @author Florian Schütz (fschuetz@ieee.org)
 * @brief Example file for BalCCon Cyberdeck modules.
 * @version 1.0
 * @date 12.09.2023
 * @copyright Copyright (c) 2022, Florian Schuetz, released under MIT license
 *
 * This module display a hello world text on the display and blinks the led's.
 * The module will terminate, whenever the user presses a button.
 */ 

#pragma once
#ifndef BCD_MOD_EXAMPLE_HPP
#define BCD_MOD_EXAMPLE_HPP

#include <FreeRTOS/portmacro.h>
#include <stdlib.h>
#include "esp_log.h"
#include "st7735_bcd.hpp"
#include "gfx.hpp"
#include "ch405labs_esp_led.hpp"
#include "ch405labs_esp_debug.h"
#include "ch405labs_esp_wifi.hpp"
#include "ch405labs_esp_controller.hpp"

////////////////////////////////////////////////////////////////////////////////
// Menuconfig options
////////////////////////////////////////////////////////////////////////////////
#define TAG_MOD_EXAMPLE CONFIG_TAG_MOD_EXAMPLE

#if CONFIG_MOD_EXAMPLE_LOG_LEVEL == 0
#define MOD_EXAMPLE_LOG_LEVEL esp_log_level_t::ESP_LOG_NONE
#elif CONFIG_MOD_EXAMPLE_LOG_LEVEL == 1
#define MOD_EXAMPLE_LOG_LEVEL esp_log_level_t::ESP_LOG_ERROR
#elif CONFIG_MOD_EXAMPLE_LOG_LEVEL == 2
#define MOD_EXAMPLE_LOG_LEVEL esp_log_level_t::ESP_LOG_WARN
#elif CONFIG_MOD_EXAMPLE_LOG_LEVEL == 3
#define MOD_EXAMPLE_LOG_LEVEL esp_log_level_t::ESP_LOG_INFO
#elif CONFIG_MOD_EXAMPLE_LOG_LEVEL == 4
#define MOD_EXAMPLE_LOG_LEVEL esp_log_level_t::ESP_LOG_DEBUG
#elif CONFIG_MOD_EXAMPLE_LOG_LEVEL == 5
#define MOD_EXAMPLE_LOG_LEVEL esp_log_level_t::ESP_LOG_VERBOSE
#endif //CONFIG_MOD_EXAMPLE_LOG_LEVEL

////////////////////////////////////////////////////////////////////////////////
// Error handling
////////////////////////////////////////////////////////////////////////////////
typedef BaseType_t mod_example_err_t; 

#define MOD_EXAMPLE_FAIL -1                              /**< Generic failure */
#define MOD_EXAMPLE_OK 0x000                             /**< All good */

////////////////////////////////////////////////////////////////////////////////
// Macros
////////////////////////////////////////////////////////////////////////////////
// Put any macro here.

////////////////////////////////////////////////////////////////////////////////
// Namespaces
////////////////////////////////////////////////////////////////////////////////
// If you "use" namespaces, put them here.

////////////////////////////////////////////////////////////////////////////////
// Various Types
////////////////////////////////////////////////////////////////////////////////
// Put type definitions that don't fit above here.

// Any module should reside in its own namespace using the scheme
// bcd_mod_<name of your module>. Please adapt to the name of your module.
namespace bcd_mod_example {

////////////////////////////////////////////////////////////////////////////
// Main function
////////////////////////////////////////////////////////////////////////////
// While not mandatory, it is customary to call the entry point into your
// module `module_main()`. It must return an integer (0 on success) and
// has a void * parameter. The void pointer can point to more complex
// structures, which allow you to pass multiple parameters.
int module_main(void *param);

////////////////////////////////////////////////////////////////////////////
// Function prototypes, classes, ...
////////////////////////////////////////////////////////////////////////////
// Put your function prototypes or class definitions etc... here.

} // namespace bcd_mod_example
#endif // BCD_MOD_EXAMPLE_HPP
```
Next we prepare the `src/mod_example.cpp` file. Replace all the `mod_template`stings by `mod_example`. As done before, you can either do this in Visual Studio Code or on the command line:
```bash
sed -i '' -e 's/mod_template/mod_example/g' src/mod_example.cpp
```
Then copy the first comment block from you `include/mod_example.hpp` and replace the first comment block in `src/mod_example.cpp`. Your file should now look something like this:
```cpp
/**
 * @file mod_example.hpp
 * @author Florian Schütz (fschuetz@ieee.org)
 * @brief Example file for BalCCon Cyberdeck modules.
 * @version 1.0
 * @date 12.09.2023
 * @copyright Copyright (c) 2022, Florian Schuetz, released under MIT license
 *
 * This module display a hello world text on the display and blinks the led's.
 * The module will terminate, whenever the user presses a button.
 */

#include "../include/mod_example.hpp"

namespace bcd_mod_example {

////////////////////////////////////////////////////////////////////////////
// Main function
////////////////////////////////////////////////////////////////////////////
// While not mandatory, it is customary to call the entry point into your
// module `module_main()`. It must return an integer (0 on success) and
// has a void * parameter. The void pointer can point to more complex
// structures, which allow you to pass multiple parameters.
int module_main(void *param) {
  
#ifdef CONFIG_DEBUG_STACK
	UBaseType_t uxHighWaterMark;

	/* Inspect our own high water mark on entering the task. */
	uxHighWaterMark = uxTaskGetStackHighWaterMark( NULL );
	ESP_LOGD(CONFIG_TAG_STACK, "mod_example::module_main(): High watermark"
		" for stack at start is: %d", uxHighWaterMark);
#endif //CONFIG_DEBUG_STACK

#ifdef CONFIG_DEBUG_HEAP
	multi_heap_info_t heap_info;
	heap_caps_get_info(&heap_info, MALLOC_CAP_DEFAULT);
	ESP_LOGD(CONFIG_TAG_HEAP, "mod_example::module_main(): Heap state at"
								" start: \n"
								" Free blocks: %d\n"
								" Allocated blocks: %d\n"
								" Total blocks: %d\n"
								" Largest free block: %d\n"
								" Total free bystes: %d\n"
								" Total allocated bytes: %d\n"
								" Minimum free bytes: %d\n"
								, heap_info.free_blocks
								, heap_info.allocated_blocks
								, heap_info.total_blocks
								, heap_info.largest_free_block
								, heap_info.total_free_bytes
								, heap_info.total_allocated_bytes
								, heap_info.minimum_free_bytes);
#endif // CONFIG_DEBUG_HEAP

// <--- PLACE CODE BELOW HERE -->  

// <--- PLACE CODE ABOVE HERE -->

#ifdef CONFIG_DEBUG_STACK
/* Inspect our own high water mark before exiting the task. */
	uxHighWaterMark = uxTaskGetStackHighWaterMark( NULL );
	ESP_LOGD(CONFIG_TAG_STACK, "mod_example::module_main(): High watermark"
		" for stack at end is: %d", uxHighWaterMark);
#endif

	return 0;
}

} // namespace bcd_mod_example
```
#### Adding the Module to the Framework
While our module does not yet do anything, this is a good time to add it to the framework and check if everything compiles as intended. For our case, our module will be added such that it shows up in the main menu and can be executed by selecting it. 

> [!NOTE] Cleaning before compilation
> When adding a new module you need to clean the project before compilation in order to enable cmake to recognise the new module. This also applies, if you change the Kconfig file or the CMakeLists file.
> To clean the project either push the little trashcan icon in the bottom bar or choose the platformio menu on the left (alien head) and then in `Project Tasks`choose `Default->General->Clean all`.

First, we need to add our module header file in the includes section of the framework. For this, open the file `src/main.hpp` from the root directory of your framework. Find the line `// <----------------------------- Modules ------------------------------------->`and add the following after the last `#include` (but before the includes of the commands).
```cpp
#include "mod_example.hpp"
```
While you are at it, you can also remove the `#include "mod_template.hpp"` as we will not need it, now that we are developing a proper module.
>[!WARNING]
>Do not add your namespace to the namespaces or your module_main() will clash and lead to compilation errors.

Next open the `src/main.cpp`file. Search for the line that says `// <--- Set up objects etc... used throughout firmware below -->`. Here we will initialise our menu object. To do this add the following code:
```cpp
gfxmenu::MenuController<lcd_type, lcd_type::pixel_type> mc;
```

Now look for the line `// <--- Register modules below -->`. Below this line add the following code:
```cpp
mc.cursor->addEntry(mc.createActionItem("Hello BalCCon",
	bcd_mod_example::module_main, NULL));
```
This registers and action item as the first menu entry. An action item is an item that is executable. In our case, the menu entry is labeled `"Hello BalCCon"`, execution starts in the `module_main(...)` function of our module and we do not pass any arguments. For more information about how to build menus consult the chapter [GFXMenu](#GFXMenu). 
Las but not least, we need to display our menu and then run a main loop. For this to happen we first add the code to display the menu in the setup section. Look for the line `// <--- Put setup code and one time acitons below -->` and add the following code below:
```cpp
// Reset cursor and select first entry
mc.cursor->setToRoot();
mc.cursor->first();
mc.cursor->selectEntry();
lcd.clear(lcd.bounds());
mc.cursor->drawMenu(lcd, srect16(lcd.bounds()), lcd_color::alice_blue,
	lcd_color::dark_goldenrod);
```
As menus are always drawn from the element the cursor points at, we must set the cursor to the first element of the root menu (aka main menu). This is done with the first two statement. Then, we want the first element to be pre-selected (third statement). Next we clear the screen and then draw the menu.
Now its time to implement the main loop. In our case, the loop simply checks if button A or button B are pressed. If they are, the currently selected menu item is executed. Pressing the buttons up or down will select the next of previous menu item. In our case, as there is only one menu item, this will not do anything but it shows you how to do it when you add more modules. Look for the line that states `// <--- Implement your main loop below -->` and add the following code:
```cpp
for(;;) {
	// Query button and execute menuitem if button A or B is pressed.
	controller.capture();
	
	if(controller.getButtonState(BUTTON_DOWN)) {
		mc.cursor->deselectEntry();
		mc.cursor->next();
		mc.cursor->selectEntry();
		mc.cursor->drawMenu(lcd, srect16(lcd.bounds()),
		lcd_color::alice_blue, lcd_color::dark_goldenrod);
	} else if(controller.getButtonState(BUTTON_UP)) {
		mc.cursor->deselectEntry();
		mc.cursor->previous();
		mc.cursor->selectEntry();
		mc.cursor->drawMenu(lcd, srect16(lcd.bounds()),
		lcd_color::alice_blue, lcd_color::dark_goldenrod);
	}
	 
	if(controller.getButtonState(BUTTON_A)
		|| controller.getButtonState(BUTTON_B)) {
		
		const gfxmenu::Entry<lcd_type, lcd_type::pixel_type> *e =
		mc.cursor->getEntry();
		if(e != NULL && typeid(*e) == typeid(gfxmenu::ActionItem<lcd_type, 
			lcd_type::pixel_type>)) {
			int return_code = ((gfxmenu::ActionItem<lcd_type, 
				lcd_type::pixel_type> *)e)->execute();
			if(return_code < 0) {
				ESP_LOGE(TAG_STATE, "Could not execute menut item. Code %d",
					return_code);
			} else if (return_code > 0) {
				ESP_LOGW(TAG_STATE, "Menu execution returned with code %d.",
					return_code);
			};
			// Need to draw menu again, as execution could have used screen
			mc.cursor->drawMenu(lcd, srect16(lcd.bounds()),
				lcd_color::alice_blue, lcd_color::dark_goldenrod);
		}
	}
	// Delay to allow user to release buttons
	vTaskDelay(pdMS_TO_TICKS(250));
}
```
In our infinite loop, we first capture the pressed keys. Capturing keys records the state of the keys at the very moment this function is called. This is the reason why the last command in the loop is the `vTaskDelay()` command which puts the main task to sleep for 250 milliseconds. The sleep allows the user to release buttons before reading them again. If this command would not be here, the loop would record a pressed button many times and for example scroll through commands very fast. Make sure to read the chapter [Controller Driver](#Controller%20Driver) for more information.
After reading the button presses from the controller, we check if the down button was pressed. If the down button was pressed, we deselect the current menu item, move the cursor one menu item down and select it. We then need to redraw the menu to reflect the change on the display. Note that this does not have any effect in our current state, as we just have one menu item.
If the down button was not pressed, we check if the up button was pressed. If this is the case, we deselect the current entry, move the cursor one item up an in the menu and select it and then redraw the menu. If neither up nor down were pressed, we finally check if the A or B button was pressed. If this is the case, we check if the active menu item is an action item. This is done by checking the object type of the menu item. If the item is an action item, we execute it and check the return code. If the return code is 0, all is good. If it is smaller than 0, execution failed and we display an error to the console. If the return code is larger than 0 we display a warning that the module returned with a non zero code. After executing, we also need to redraw the menu, as the module may have changed what is displayed on the screen. Make sure to read the chapter [GFXMenu](#GFXMenu) for more information on how to build an navigate menus.
The code above successfully registers our module in a menu that is displayed on the cyberdeck and can be executed. Your can test this by compiling the module and flashing it to your cyberdeck. To do this, select Platformio in the left menu bar (the alien head). Then in the `Project Tasks` open the folder `BCD-0o27-5KY`. Wait for the project to self configure and then first clean the project by choosing `Genreal->Clean All` and then choose `General->Build` to build the project. If everything compiles fine, attach your cyberdeck to your computer using a USB-C cable and choose `General->Upload`. This flashes the firmware to your cyberdeck. Before doing this, make sure you do not have any serial console open that is connected to your cyberdeck. Otherwise flashing will fail.  
When you move up and down in the menu or execute the module you will see a short flicker, as neither the module does anything yet nor are there other menu items to scroll through.
If all of this is working, move on to the next chapter, where we finally implement the functionality of our module.
#### Implementing the Module - Part 1: Hello BalCCon
>[!INFO] Relative line numbers
>For the rest of this tutorial we are going to reference to line numbers relative to anchor points, because if you used longer descriptions in the preparation chapter, your line numbers culd differ. To enable relative line numbers in Visual Studio Code you can go to `Settings->Settings`. Search for "line numbers" and choose `relative`. You can jump to a specific line number pressing `CTRL+G`. 
>Alternatively you can just calculate the relative line numbers in your head and stick with the default.

For our module, we want to display the message "Hello BalCCon" in the middle of the screen and display the BalCCon logo as a background image. We also want to overlay some lines as an animation and blink the leds.
Lets start with the easy part, displaying the text all centred. Open `/modules/mod_example/include/mod_example.hpp` (relative to your framework root). From now on, we will no longer provide the full path in this chapter. All paths will be relative to the module root (`/modules/mod_example`). Search for the line `// <--- PLACE CODE BELOW HERE -->`. Then start by writing the following code below:
```cpp
#ifdef CONFIG_DISPLAY_SUPPORT

// First check if a display is supported
//
// Our module will require a display and will return an error if a display
// is not supported.
if(!bcd_sys.displaySupport()) {
	ESP_LOGE(TAG_MOD_EXAMPLE, "This module requires a working display.");
	return MOD_EXAMPLE_FAIL;
}

// Get refferences to display and font
lcd_type &lcd = bcd_sys.getDisplay();
const gfx::font& font = bcd_default_font_FON;

// Prepare the text and measure its dimensions.
const char* hello_balccon_txt = "Hello BalCCon";
gfx::srect16 hello_balccon_txt_rect =
	font.measure_text((gfx::ssize16)lcd.dimensions(),hello_balccon_txt).bounds();

//Clear the display and draw the text in the center.
lcd.clear(lcd.bounds());
gfx::draw::text(lcd,
	hello_balccon_txt_rect.center((gfx::srect16)lcd.bounds()),
	hello_balccon_txt,
	font,
	gfx::color<typename lcd_type::pixel_type>::chartreuse);

// Delay for 5 seconds
vTaskDelay(pdMS_TO_TICKS(5000));

#else //CONFIG_DISPLAY_SUPPORT

ESP_LOGE(TAG_MOD_EXAMPLE, "This module requires display support.");
return MOD_EXAMPLE_FAIL;

#endif //CONFIG_DISPLAY_SUPPORT
```
For referencing line numbers, the first line stating `#ifdef CONFIG_DISPLAY_SUPPORT`is referenced to as line number 1.
In this code we make some fundamental decisions about our module. The most important one is, that our module should only run on a cyberdeck which has a working display. At the time of writing, all cyberdecks have a display, but in the future, maybe there will be some low power cyberdeck variants without. In the configuration of the firmware display support can be deactivated for cyberdecks without displays (see [Cyberdeck Configuration](#Cyberdeck%20Configuration) for more information). If the configuration is set to no display, then the definition `CONFIG_DISPLAY_SUPPORT` is not present. This allows us to ensure code that uses the display is only compiled if the hardware we compile for actually supports a display. If not, the code size will be significantly smaller. Therefore, all our code that uses display functionality should go in between `#ifdef CONFIG_DISPLAY_SUPPORT ... #endif` preprocessor statements.
Unfortunately, there is also a second case we need to check. Even if a display is supported its initialisation may have failed during startup. We can test for this querying `bcd_sys.displaySupport()`. If the display works as expected, this function call will return true. 
As we made the decision that our module will only run if a display is supported and functional, we display and error in case a display is not supported (in the `#else` case of the preprocessor check) or the display is not function (line 7-10) and then return MOD_EXAMPLE_FAIL as an indicator for failure.
Once we established that we have a working display, on line 13 we get a reference to the display. We will need to pass the display as a parameter to the drawing functions we use. A reference in c++ stores the address of the variable it references. It can be seen as a non-NULL pointer. Syntactically it can be used like regular variables or objects and does not require dereferencing. If you want to know more about c++ references then [Microsoft - References in C++](https://learn.microsoft.com/en-us/cpp/cpp/references-cpp?view=msvc-170) is a good starting point.
To draw text, we also need a font. The BCD-0o27 comes with a default font. For ease of use we get a reference to this default font. On line 17 we define our text and then on line 18 measure it. This is necessary as when we draw text on the display, we always define a rectangle where to draw to. This can be all of the display, or any part of it. If the text is longer than this rectangle (and the rectangle is high enough to display more lines), the text is automatically wrapped. In our case, we want to make sure to draw to a rectangle just big enough to hold all of the text on one line. The function `font.measure_text(...)`does exactly that. Note, that this function on the one hand will also give you the correct size, in case your text includes line breaks (`\n`) and will also take into account as a parameter the maximum area for your layout (which in our case is the size of the display). If you want to know more about fonts, consult [honey the codewitch gfx - Fonts](https://honeythecodewitch.com/gfx/wiki/fonts.md).
Finally its time to draw on the display. We first need to clear the display to remove anything that is currently displayed. This is achieved with the function `lcd.clear(...)`. This function takes a rectangle to clear as a parameter. We want to clear the full screen and therefore pass the boundaries of the display as a parameter. Next we draw our text on the screen using the `gfx::draw::text(...)`function. As a first parameter we need to pass a reference to the source to draw to, which in our case here is the lcd. Next we need to define the rectangle to draw into. This rectangle is the size of the text offset in such a way that its center is at the center of the display. This can be achieved using the `.center(...)` function on the rectangle we measured before. This function takes the parent rectangle as a parameter, which in our case is the boundaries of the lcd. The next argument is the actual text to display, the font to use for displaying it and the color in which the text should be displayed. To learn more about colors refer to [honey the codewitch gfx - Pixels / Colors](https://honeythecodewitch.com/gfx/wiki/pixels.md#1.3). 
After having drawn the text on the display, we simply wait for 5 seconds, until our module terminates successfully.
Go ahead and compile and upload the framework to your cyberdeck to test you code. To do so, in the left menu choose platformio (the alien head) and then choose `General->Build`. Wait for the build to complete and then choose `General->Upload` with your cyberdeck connected to usb and switched on. Wait for the deck to reboot and you can now see the menu entry for your module on the deck and start it.
#### Implementing the Module - Part 2: LED blinking
TODO
#### Implementing the Module - Part 3: Displaying an Image
TODO
#### Implementing the Module - Part 4: Drawing Lines
TODO
#### Compiling the Release Version
TODO

> [!NOTE] Using submodules in your module
> A note about using submodules in you module: In case your submodule has other submodules, you also need to intitialise those using the `git submodule update --init` command in the directory of your module.

## Console Commands

## Cyberdeck Configuration
### Main Stack Size
TODO - explain stack of main task
The main task stack size depends heavily on how many modules and commands you use in your custom firmware and how much memory in the main task they require (some modules and commands may spawn own threads with their own stack). If you prepare a firmware, make sure to set the `CONFIG_ESP_MAIN_TASK_STACK_SIZE` in `menuconfig` accordingly. Also, it is recommended to add the appropriate stack size to the `sdkconfig.defaults`. 

> [!warning]
> Setting the value in `sdkconfig.defaults` does not overwrite existing configurations. It will rather take effect, if there is no existing configuration. So if you make that change during development, you need to set your `menuconfig` option anyways.
### Partition Table
Set the partition table in menuconfig. Set `custom_partition_table` to `partiontions.csv`. Set `Offset of partition table` to `0x8000`. 

> [!info]
> When using verbose logging or higher for the bootloader, it might be necessary to move the partition table to 0x10000 to make enough space for the bootloader.

## Preparing Firmware for Flashing / Delivery
Once firmware is final, potentially many devices need to be flashed. It is cumbersome to do this through the development environment. It is recommended to prepare the firmware as a binary package ready for flashing. To do this with platformio, first create a release profile if you haven't done so yet:
```

```
Next build the firmware in the development environment, just to make sure everything is fine. After all is set up correctly in the platformio core cli the following command will allow us to identify the needed parameters to build the project:
```bash
pio run -v -t upload
``` 
Depending on your setup, you might need to get the idf framework first by issuing `get_idf`. Also make sure you have a cyberdeck attached as the flash command should be able to execute.

The project is now being built giving verbose output. Towards the end, there will be the flash command with all parameters. The output may look something like this:
```bash
"/Users/fschuetz/.platformio/penv/bin/python" "/Users/fschuetz/.platformio/packages/tool-esptoolpy/esptool.py" --chip esp32s3 --port "/dev/cu.usbserial-1430" --baud 460800 --before default_reset --after hard_reset write_flash -z --flash_mode dio --flash_freq 80m --flash_size 16MB 0x0 /Users/fschuetz/Development/balccon_badge_workbench/checked_out_branches/firmware-design/balccon-badge/firmware/BCD-0o26_framework/.pio/build/BCD-0o26-5KY/bootloader.bin 0x8000 /Users/fschuetz/Development/balccon_badge_workbench/checked_out_branches/firmware-design/balccon-badge/firmware/BCD-0o26_framework/.pio/build/BCD-0o26-5KY/partitions.bin 0x10000 .pio/build/BCD-0o26-5KY/firmware.bin
```

### Some things to consider
TODO - Full clean wipes menuconfig. Add rtti and adapt main task stack size.
# Drivers and Libraries
# Framework Development
## Drivers
TODO
### Controller Driver
TODO
## Libraries 
TODO
### HTCW GFX
TODO
Display routines are provided by the htcw gfx library as templates. This means we need to provide the type of our drawing target (usually the display or a bitmap that we later display) as a parameter. Due to the nature of templates in c++ this means, we want to implement our routines that use gfx also as templates to enable them being used with any drawing target. To learn more about how gfx works please refer to chapter [HTCW GFX](#HTCW%20GFX). If you would like to better understand, why c++ templates need their implementation in the header (and how you could do it differently) this question / answer  [about c++ template implementation on Stackoverflow](https://stackoverflow.com/questions/495021/why-can-templates-only-be-implemented-in-the-header-file) can point you in the right direction.
### GFXMenu
TODO
## Components
TODO

# Graphics
## Displaying images
### Converting images into header files
```
https://github.com/jimmywong2003/PNG-to-RGB565
```

# Appendix
## Getting the Framework
The framework is hosted as a git repository at https://gitlab.com/fschuetz/bcd-0o27.git. The repository makes heavy use of submodules, as many components for the BCD-0o27 are developed in parallel.
To create a local repository using git follow these steps:
```bash
git clone --recurse-submodules https://gitlab.com/fschuetz/bcd-0o27
```

## Setting up the Development Toolchain
In this chapter we will show how to set up the development environment consisting of git, espidf, Microsoft Visual Studio Code and Plattformio. If you are an experienced user, feel free to use the IDE of your choice.
### Installing GIT and cloning the repository
We will use git from the command line, as we have to deal with submodules, which are not well supported in the Visual Studio Code IDE.
If you have git already installed, you can skip this step.
1. Install git for your platform. Follow the guide at [Gitlab](https://docs.gitlab.com/ee/topics/git/how_to_install_git/)
2. Clone the repository: 
    ```bash
    git clone --recurse-submodules https://gitlab.com/fschuetz/bcd-0o27
    ```
Some tips on working with submodules, in case you run into a head detached situation: https://stackoverflow.com/questions/18770545/why-is-my-git-submodule-head-detached-from-master

### Install Microsoft Visual Studio Code (VSCode)
1. Install [VSCode](https://code.visualstudio.com/) for your operating system.
2. Open VSCode.

### Install C/C++ and PlatformIO Extensions
1. In VSCode: Open the "Extensions" side bar on the left side.
2. Search for the "C/C++" extension by Mircrosoft and install it.
3. Search for the PlatformIO IDE by PlatformIO and install it. See [PlatformIO IDE for VSCode](https://docs.platformio.org/en/latest/integration/ide/vscode.html#ide-vscode)
4. Once installation has finished, restart VSCode

### Build and Upload the Firmware 
In this chapter we will build the filesystem image and the firmware and upload both to the badge. If this works, then you can start developing your own firmware using the framework. For testing we highly recommend, taking the example in the directory `firmware/example` rather than the framework, as the example will give you running firmware that allows you to see something actually happening.
1. Start Microsoft Visual Studio and make sure you are in a new window, with no project loaded.
2. Select the alien head in the left bar (Platformio menu)
3. A left band appears. Select the blue button "Pick a folder"
4. From the cloned repository choose the `firmware/example` or the `firmware/framework` folder (as written above, its recommended to start with the example rather than the plain framework).
5. Click open.
6. Wait for platformio to configure itself. This is IMPORTANT: Between now and building the file there might raise popups in the bottom left corner asking you to install extensions or configurations. Usually you are asked to intall C++ specific extensions and CMake specific extensions. Confirm all of them. For CMake, if asked, you can "scan for kits". Scan for kits may also go away on itself, then everything is fine as well. 
7. If all went well so far you will recognise a blue ribbon / button on the bottom and some symbols like a home, a checkmark, roght pointing arrow etc.. If there is the message "Platformio: Loading tasks..." wait until it disapears. (this may take a long while). PlatformIO will automatically configure the project.
8. Open the file main.cpp in the "src" folder.
9. In the bottom task list (with the blue ribbon / button and the checkmark etc...), first choose the build environment by clicking on the symbol that looks like a folder and says "Switch Platformio Project Environment" if you hover over it. Usually it reads default right to the symbol. Choose `env:BCD-0o27-5KY` (or the `env:BCD-0o27-5KY-release` if you want to build for release rather than debug - if unsure make a debug build).
10. Now select the checkmark to build the project. This builds the project. Dependencies are pulled in automatically. In case Platformio does not pull in the Espressif 32 framework, follow the steps in the note below to install it manually.
11. If the project builds successfully, connect your badge to the computer using a usb-c cable (make sure it is actually a data cable and not just a charging cable)
12. Make sure the device is recognised. If the device is not recognised and a com port assigned, you might have to install a driver for the CH340 serial bridge. Follow the instructions from [Sparkfun](https://learn.sparkfun.com/tutorials/how-to-install-ch340-drivers/all#drivers-if-you-need-them)
13. Once the device is recognised, in VSCode we will build the file system image, upload it and then upload the code.
14. From the side bar choose the PlatformIO icon (alien head)
15. Select BCD-0o27 -> Plattform -> Build Filesystem Image
16. When finished, select BCD-0o27 -> Platform -> Upload Filesystem Image (BCD-0o27)
17. When finished, select the right pointing arrow ("Platformio: Upload") in the blue ribbon at the bottom. The project will be built and uploaded to the badge.
18. Either launch the serial console from the blue ribbon by selecting the plug icon ("Platformio: Serial Monitor") or use minicom (preferred). Note, that the Platformio Serial Monitor may display some strange characters or double print the prompt as it does not fully support the output mode. IMPORTANT: Due to a bug, the serial console only works for input if the connection was made at badge startup. If you do not see a prompt, leave the console on and restart the badge by pushing the power button (left between display and battery holder).
19. CRITICAL: Make sure, that you DO NOT have a serial monitor running when trying to flash the badge. This will lead to flash failure (for both, filesystem and firmware).

Note: The Espressif 32 framework should install automatically when building the project. If this is not the case, you can install it manually:
1. Open the Platformio sidebar (left side, alien head icon).
2. Select PIO Home -> Platforms
3. Click on the "Embedded" tab. Search for "Espressif 32" and click it.
4. Install the latest version. (At the time of writing this is version 5.1.0. While we plan to adapt the framework to newer versions, you might want to select this version if the newest version is not working due to breaking changes.)
5. Once the installation has completed confirm the success dialog.
### Helpful Resources
[Espressif 32 for Platformio](https://docs.platformio.org/en/latest/platforms/espressif32.html)

## Misc notes - ignore please
### Upload firmware directly
```bash
esptool.py --chip esp32s3 --port "/dev/cu.usbserial-1430" --baud 460800 --before default_reset --after hard_reset write_flash -z --flash_mode dio --flash_freq 80m --flash_size 16MB 0x0 /Path/to/toplevel/dir/.pio/build/BCD-0o26-5KY/bootloader.bin 0x8000 /Path/to/toplevel/dir/.pio/build/BCD-0o26-5KY/partitions.bin 0x10000 .pio/build/BCD-0o26-5KY/firmware.bin
```

### VSCode - Git limits
Might want to change the default 10 to a higher number
```
Git: Detect Submodules Limit

Controls the limit of git submodules detected.
```

### Updating mirrors 
Go to lib directory of mirror
```
git fetch upstream 
git merge upstream/master
git push
```

### Updating submodules
```
git fetch
git pull
```

# Coding Style
TODO - very incomplete
## Line length
A line of code should not be longer than 80 characters.
```c++
ESP_LOGE(TAG_MODULE_NAME, "This is a rather long error message."
		"It should be spred on two lines");
```
If functions too long, spread on multiple lines. Two lines, indent second line by one tab and finish the line with closing bracket and ;. If more than two lines use one argument per line and close on a separate line as follows:
```c++
myfunction_with_many_arguments(
	argument 1,
	argument 2,
	argument 3)
```

## Comments
Comments for single items should either come on a separate line before the item to comment or after the item to comment but indented to character 81 and not longer than 39 characters.
```cpp
// Comment for item 1
item1();

item2();                                               // starts at character 81
```

## Future Developments
- [ ] GFX_MENU: Remove using statements from header.
- [ ] CONSOLE: Fix bug in console: Spawn whether connection present or not. (in sage mode without ansi)
- [ ] ST7735 Driver: Introduce suspend through buffering bmp
- [ ] ST7735 Driver: Remodel into proper object that allows getting an instance.
- [ ] Check compilation without display, led or controller and unify naming scheme
- [ ] CONSOLE: Redesign such that it can be deactivate (eg. if there is no serial capability)
- [ ] WIFI: Check if controller needs to be singleton or not (and clean implementation)

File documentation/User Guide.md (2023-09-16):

Version: 0x00
Applies to: HW Rev. 0x06, FW Rev. 0x01

> [!warning] Safety considerations
> NEVER lay your badge onto a metallic surface. The solder joints on the back of your cyberdeck may conduct and create a short circuit that damages its components. To secure your cyberdeck against this you might want to apply some hot glue.
> 
> Do not put the battery in reverse. The cyberdeck features some protection against this, but better safe than sorry. The cyberdeck uses LiFePo4 batteries, which are safer to use than LiPo batteries. Never use a LiPo battery in the badge. It will likely damage as the badge runs it down to 2.5V. Also read the chapter [[#Charging]].
> 
> Although it always rains in our cyberpunk future, your cyberdeck is not waterproof. Please do not use in wet environments. If you want to secure it against accidental spills, you could apply Plastik 70 spray. Make sure to cover contacts and the display before spraying.

> [!info] Important information
> If your cyberdeck does not power on, it is very likely that you need to kickstart it by giving it a charging impulse over USB-C. The protection chip may need this to wake up. This usually only happens when the battery was fully discharged or it was removed.
> 
> Currently there is a bug in the console driver. The serial console, which can be accessed using the USB-C connector does not properly initialise if you do not have a serial connection open during startup. Serial messages will be printed just fine, but input will not be processed. To fix this, plug in the running cyberdeck and open the serial terminal of your choice. Connect to the cyberdeck and then push the reset button on your cyberdeck (left button between the display and the battery) to restart.
# Getting started
If you did not build your cyberdeck yourself, jump right ahead and just use it. However, if for any reason you do not yet have a firmware installed, get your favourite firmware and consult the  [[Development Guide]] how to flash it. 
Also notice that cyberdecks are personal. The default firmware will provide you with some fun, but the main intention of the cyberdeck is to enable you to make it your own by customising the firmware with your own ideas. 
# Charging
To charge the cyberdeck, use a usb-c cable and plug it either in a charging socket or computer. The default charging will be safe with any usb port that can deliver 500mA of current. 
The cyberdeck also support charging with 1.5A of current. To enable this, unplug your cyberdeck and set jumper JP1 (close to the usb-c connector). However, be careful. If you hook your badge up to a port that does not support delivering this amount of current you might overload the upstream system and - worst case - damage it (never seen that happening, usually it just fails to deliver the current, but you have been warned). 
If you fail to unplug the cyberdeck before closing jumper JP1, the upstream device likely will not notice the increased current requirement and continue to deliver the 500mA. In that case, charging behaviour is undefined (but most likely it will just continue charging with 500mA).
# Booting
When you switch on your cyberdeck, it will start to initialise the drivers for the hardware. You can see the status of driver initialisation by the leds and - if present - the lcd screen. If any of the drivers fails to initialise this is shown by the leds and - if your badge supports a display and it is running - on the display. There are two kinds of failures: "critical failures" and "failures". 
A critical failure means that your cyberdeck cannot function and will not continue to boot. This is indicated by all leds turning red and a red "FAIL" status on the display. 
A failure means that your cyberdeck will start up just fine but that the functionality may take an impact. For example, if the display fails, you will still be able to use the console but any module that uses the display will not function properly. Normal failures are indicated by the led associated to the affected hardware capability turns yellow and - if a display is supported and is running - by a yellow fail message on the display.
The driver initialisation sequence is as follows:
- Led driver
- Display driver
- Controller driver
- Filesystem driver
- UART / console driver
- WiFi driver
If your bootup is all green, the move on to the next chapter.
## Troubleshooting
If any of the drivers fails during bootup, then you may try the following to resolve the situation:
- **Led driver**: 
	- The led driver cannot detect the presence or absence of the hardware. This means that if the driver initialises correctly but your leds malfunction, there is likely a hardware fault such as a cold soldering joint, a damaged WS2812B led or a damaged trace. Note that WS2812B leds forward data to the next led in the chain, so if multiple leds are not functioning it may be that only the first in the chain is the culprit.
	- Another reason why the led driver may fail is that the initialisation of the driver failed due to the general input / output (GPIO) of the esp32 not functioning properly or because the remote control transceiver (rmt) of th esp32 does not work properly. Last but not least, if concurrent use of leds is enable (which it is by default) the allocation of the memory necessary to run the threads may have failed. In all of these cases, the developer of the firmware might be able to help.
- **Display driver**:
	- The driver can neither detect the presence or absence of a display, nor the proper functioning of it. The driver will however check the proper functioning of the spi bus and abort with a critical failure if the spi bus is not working as intended.
-  **Filesystem**:
	- The filesystem is initialised in two steps. First non volatile storage (NVS) is initialised. NVS is needed by the WiFi and potentially other features to store small configuration parameters. If NVS initialisation fails because there are no more free pages, NVS is erased and initialisation retried. If NVS still fails, the bootup sequence aborts with a critical failure. This could be due to a hardware failure or error in the firmware.
	- In the second step, the SPIFFS filesystem is initialised. SPIFFS initialisation may fail due to various reasons. However, most likely the filesystem partition was not properly created and data not uploaded. This can easily be fixed by re-uploading the spiffs partition. Check the [[Development Guide]]. SPIFFS failures are not critical and will continue bootup. However, your cyberdeck may have severe functionality reductions.
- **Controller driver**:
	- If controller driver initialisations fails, this is a non critical failure. Functionality will be impacted, but your cyberdeck will start up and you will still be able to use the console.
	- The controller driver cannot detect hardware failures of the buttons or the shift register. If driver initialisation fails this is likely due to gpio configuration failing.
- **UART / console driver**:
	- NOTE: The console currently has a bug. It will only spawn if your are connected with your terminal software during startup. 
	- UART / console initialisation may fail due to various reasons. None of these failures is critical. If an error occurs, the cyberdeck will continue startup and run without serial console support. 
- **WiFi driver**:
	- The WiFi driver may fail, but its not a critical failure. Bootup will continue without wifi support.

# Controller
The controller layout features four buttons on the left hand side and four buttons on the right hand side.
```
        up                       Y
        O                   X    O
                            O
left O     O right
                                 O
        O                   O    B
       down                 A     
```
While custom firmware / modules may redefine how buttons are used, normally the left hand side is used for navigation and the right hand side for selection. This is why buttons are named as shown above.
# Navigation
Likely, the firmware on your cyberdeck will display a menu after startup. You can navigate the menu up and down using the top and bottom button on the left hand side of the controller.  
Menu entries are either executables - so called action items - or submenus. To execute a menu item or enter a submenu press one of the bottom row buttons of the right hand side of the controller  (button A or button B). Usually buttons X and Y (top row of right hand side of the controller) are used to leave a submenu or terminate execution of an action item. Note that action items do not need to follow this convention, so make sure to read the instructions.
# Modules
A module of the cyberdeck is a unit of functionality. Usually a module is activated by starting it in the menu on the display, using your pushbuttons A or B of the controller. It follows a description of the preinstalled modules of your firmware (make sure the revision of your firmware matches the revision of this guide).
> [!info] Rumor has it...
> ...that there is some hidden functionality that needs unlocking first.
## Sneaky & Mousy
TODO
## Logo Slideshow
TODO
## Party
TODO
## SAO Test
TODO
## Demo Mode
TODO
## Connect WiFi
TODO
# Console
TODO

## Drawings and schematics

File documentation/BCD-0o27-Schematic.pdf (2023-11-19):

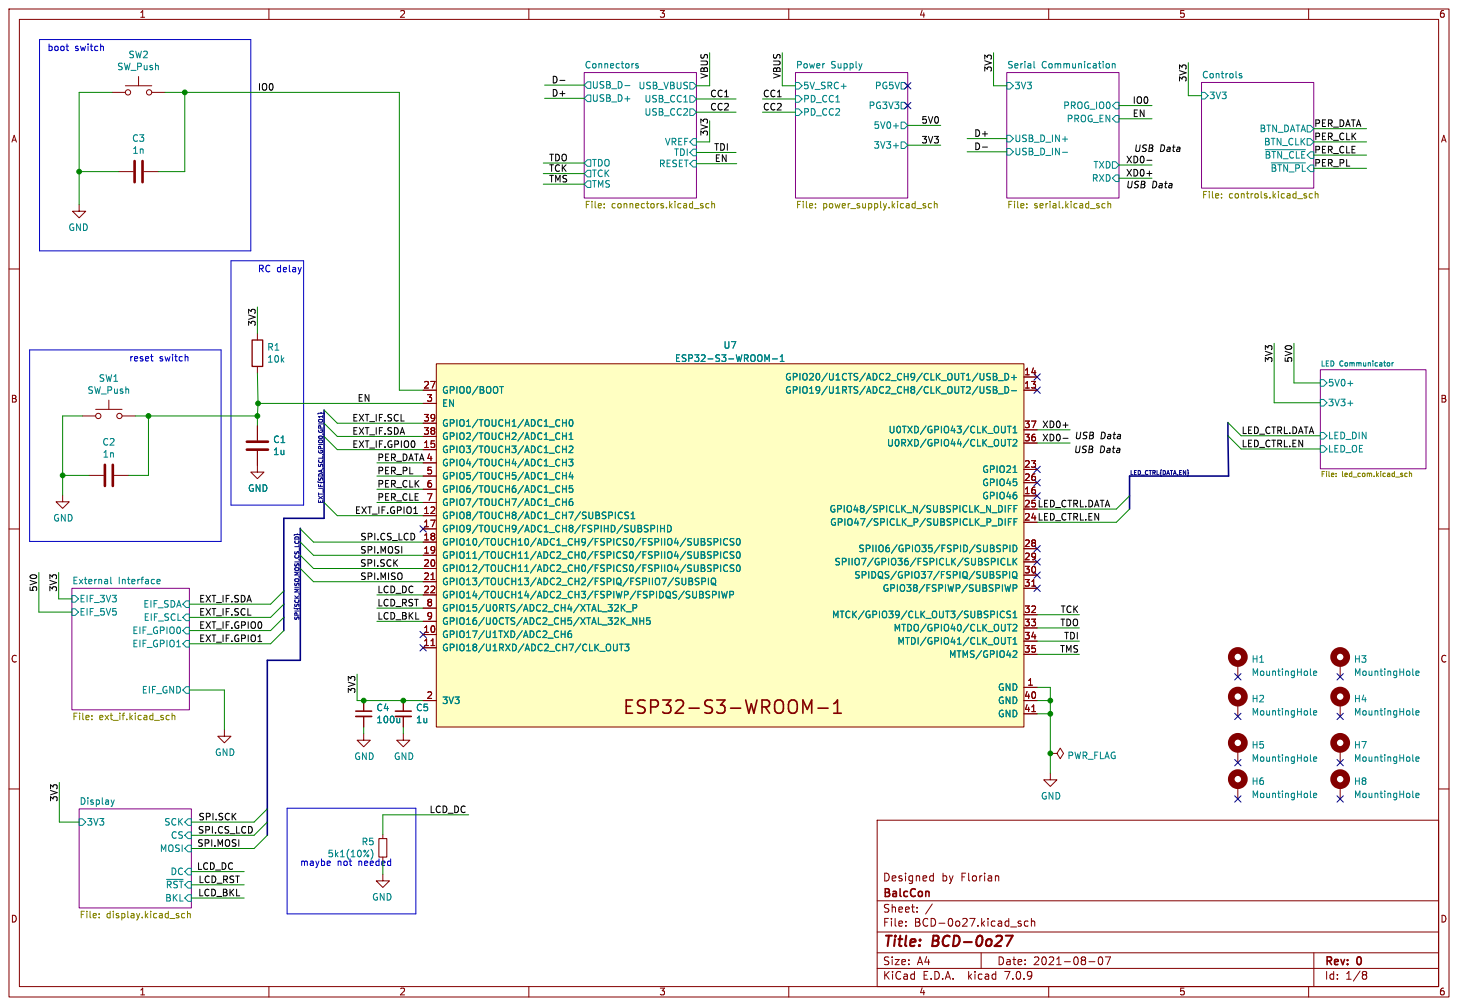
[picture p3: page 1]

GND
EIF_SCL EIF_GPIO0 EIF_GPIO1 External Interface File: ext_if.kicad_sch~{RST} DC MOSI SCKCS

LCD_DC SPI{SCK,MISO,MOSI,CS_LCD}

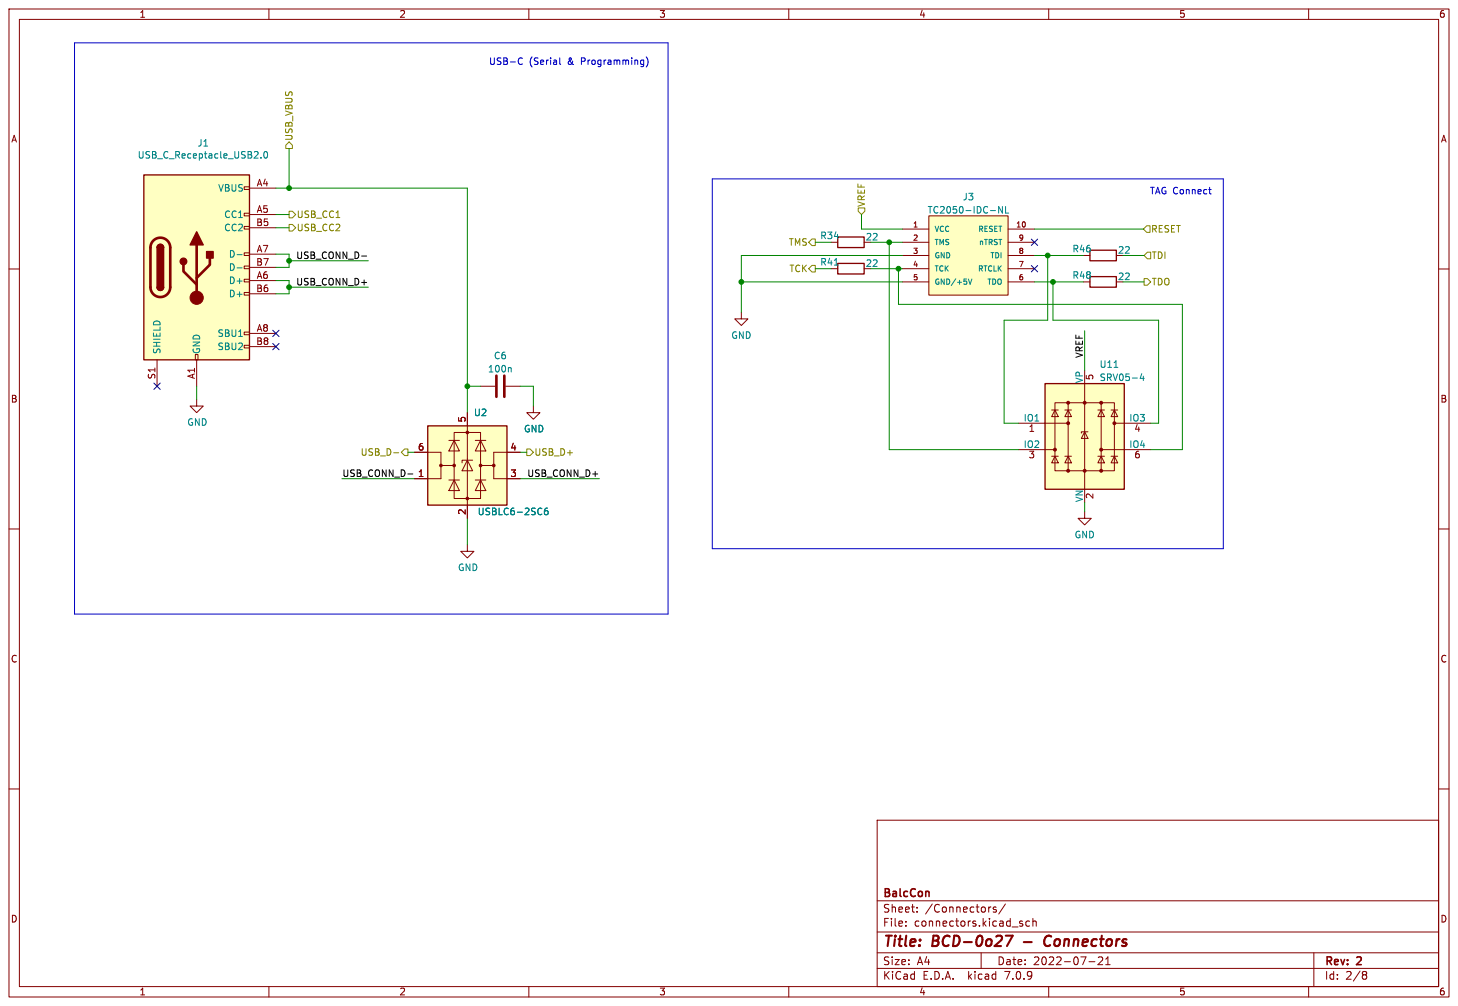
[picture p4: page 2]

File: connectors.kicad_sch Sheet: /Connectors/ BalcCon

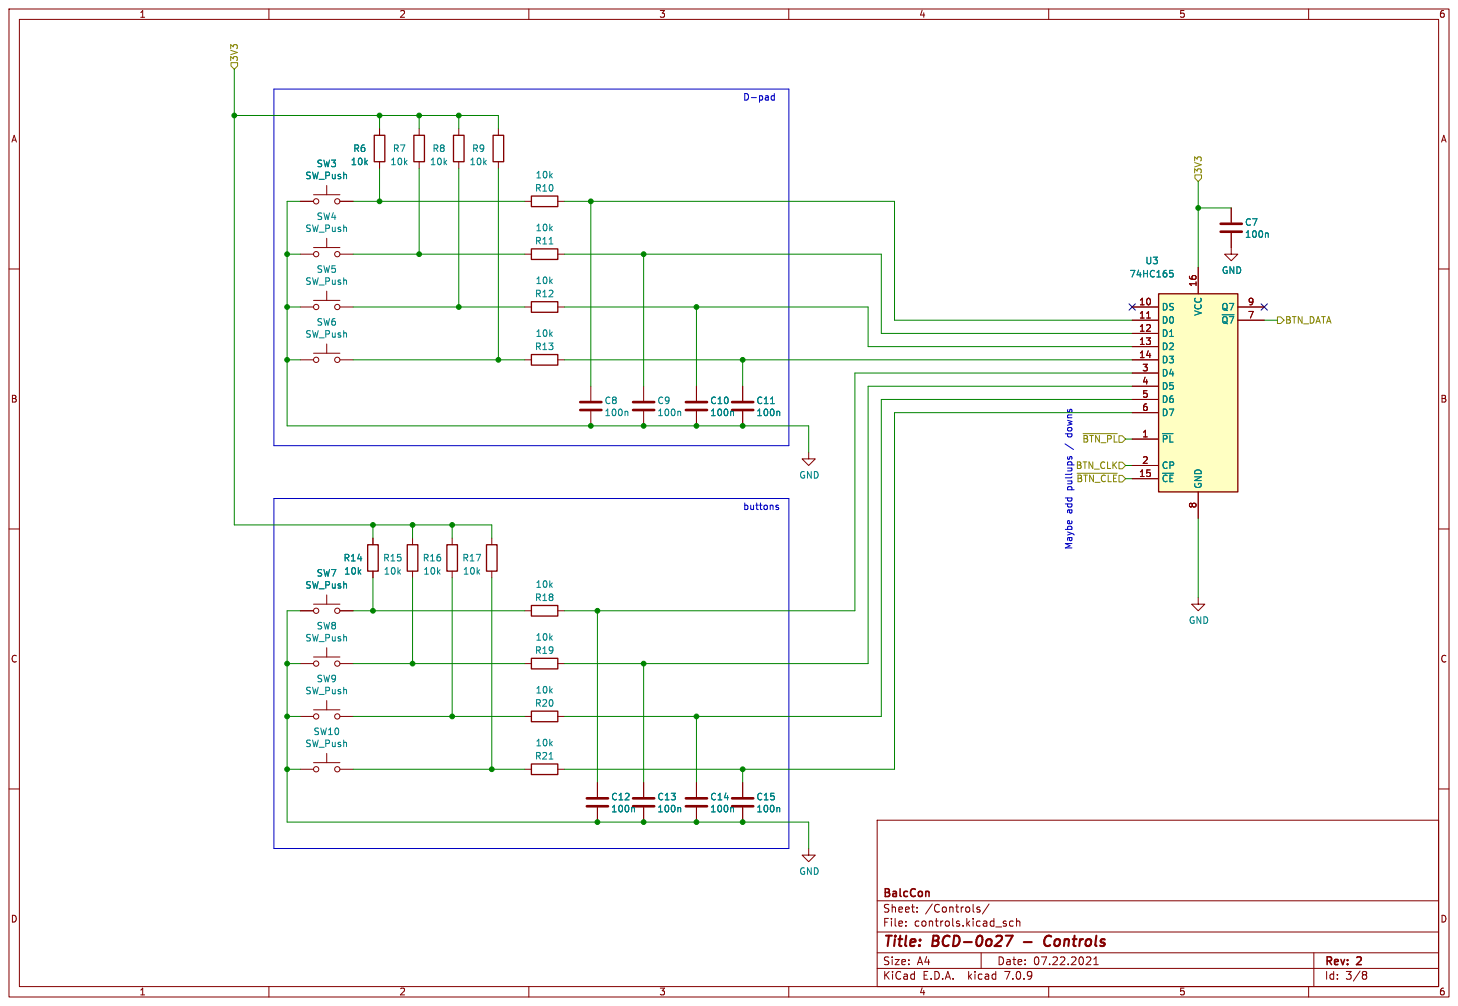
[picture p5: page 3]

File: controls.kicad_sch Sheet: /Controls/ BalcCon

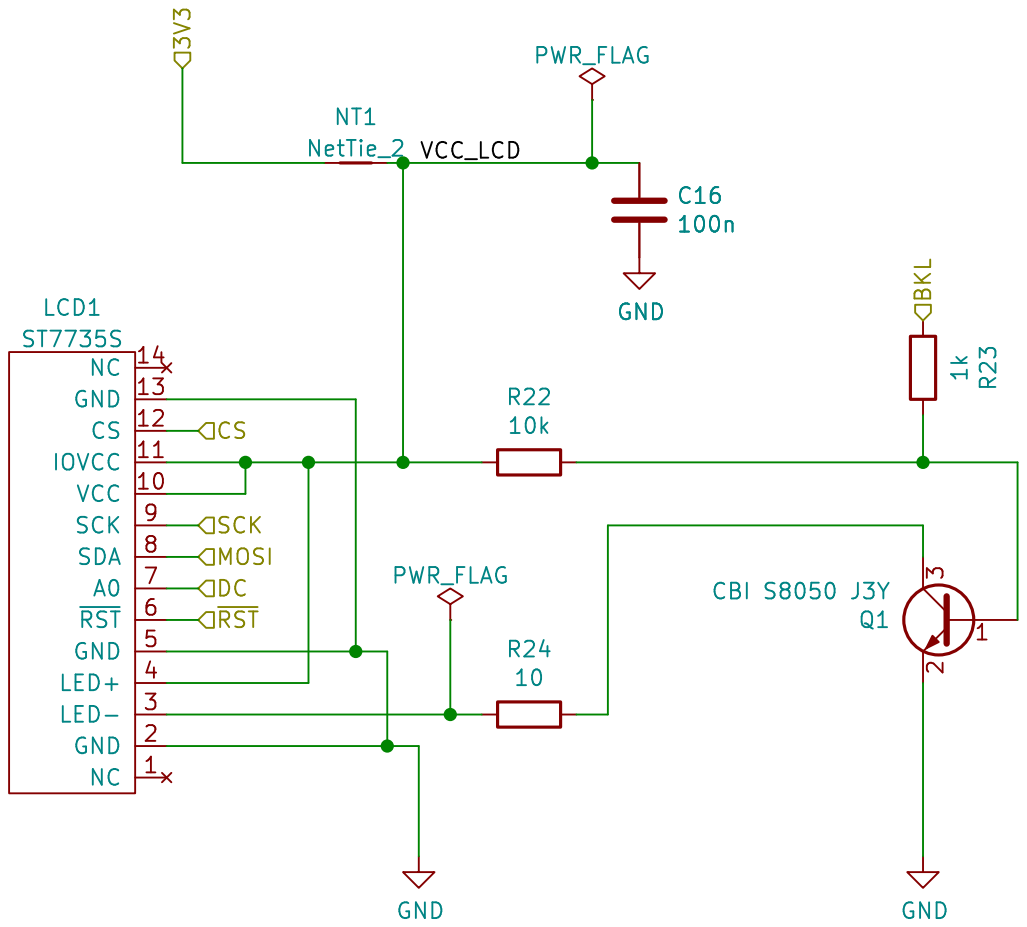
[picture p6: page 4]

2 3 Q1 CBI S8050 J3Y GND R23 1k 3V3 MOSI ~{RST} DC

File: display.kicad_sch Sheet: /Display/ BalcCon

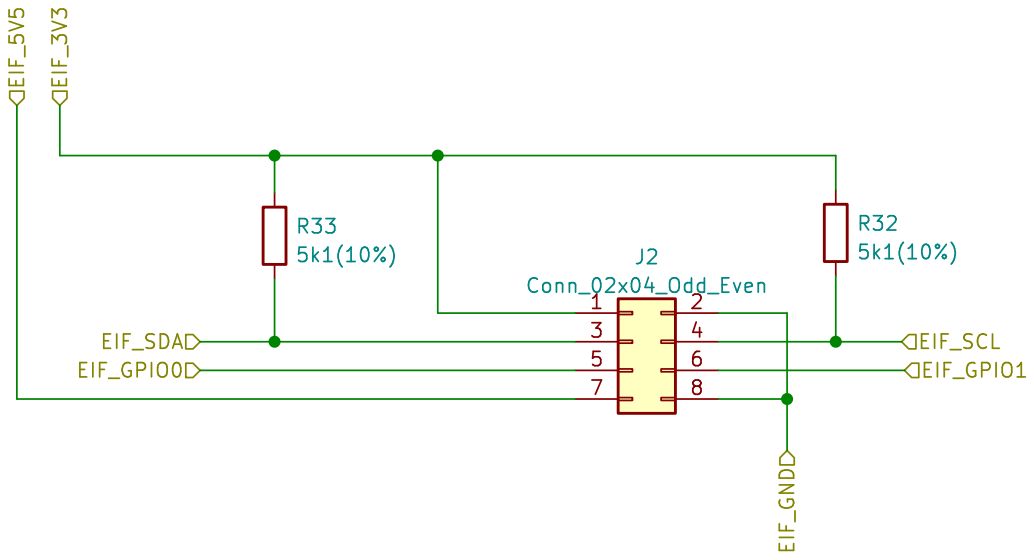
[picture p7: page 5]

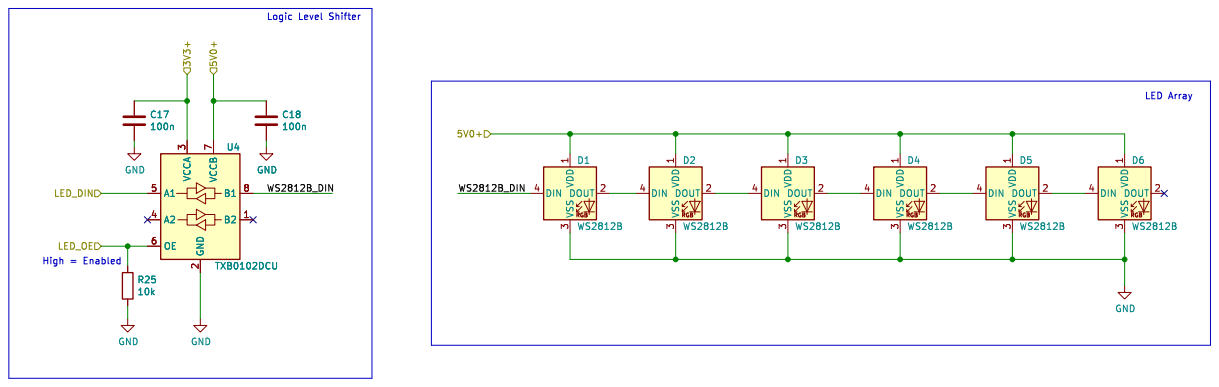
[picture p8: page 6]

Florian Schuetz
File: led_com.kicad_sch Sheet: /LED Communicator/ BalcCon

Id: 6/8 Title: LED Communication

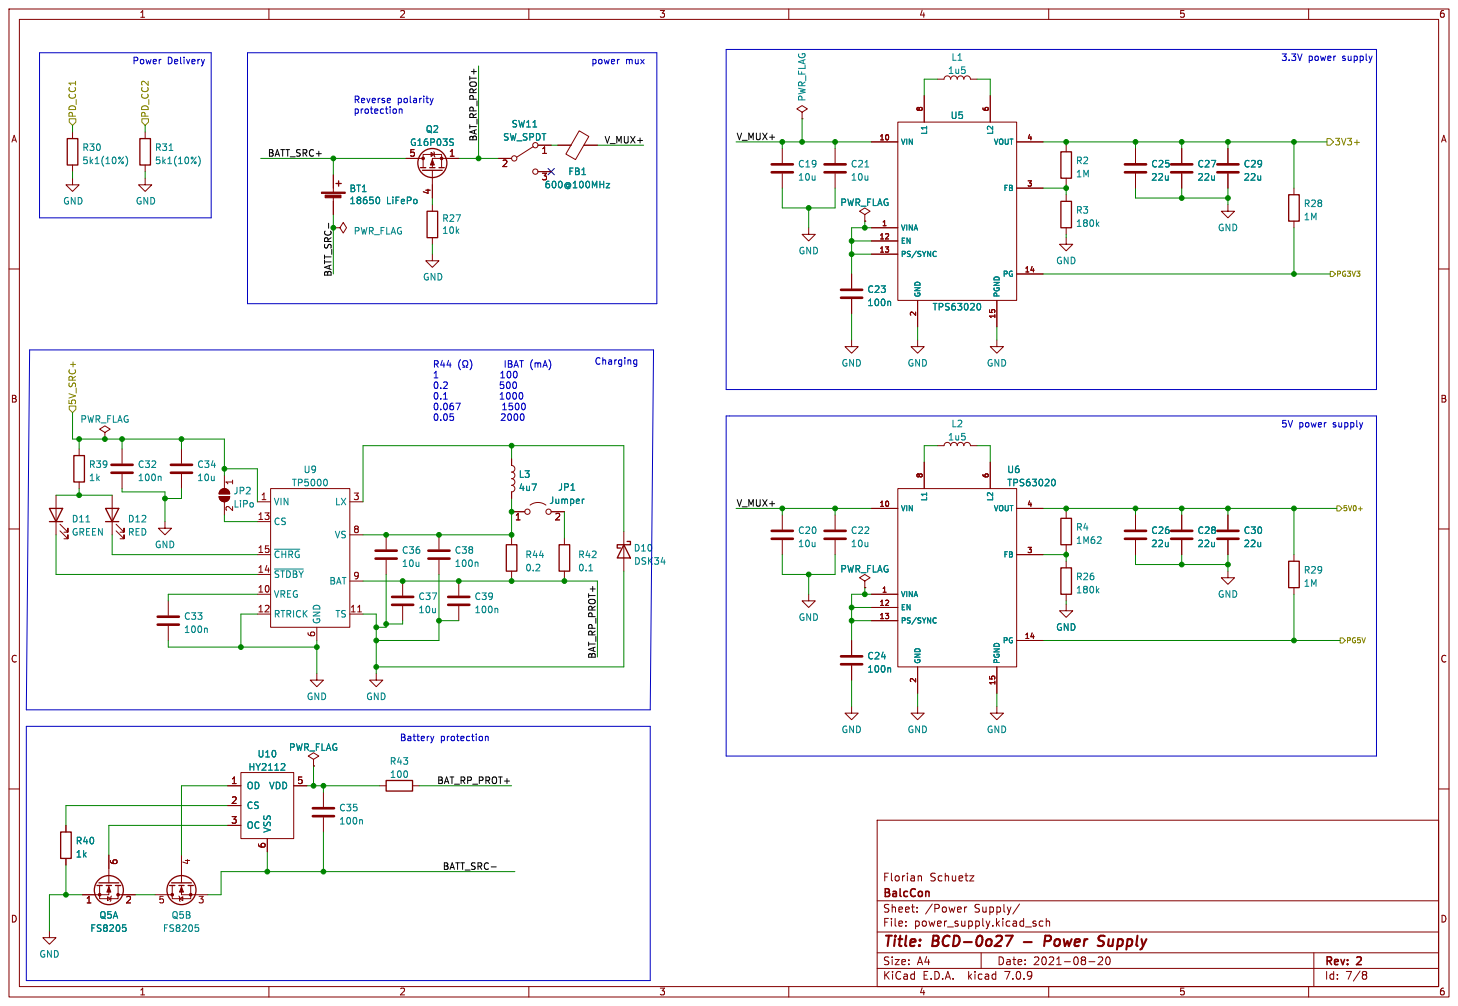
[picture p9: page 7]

5V power supply Reverse polarity

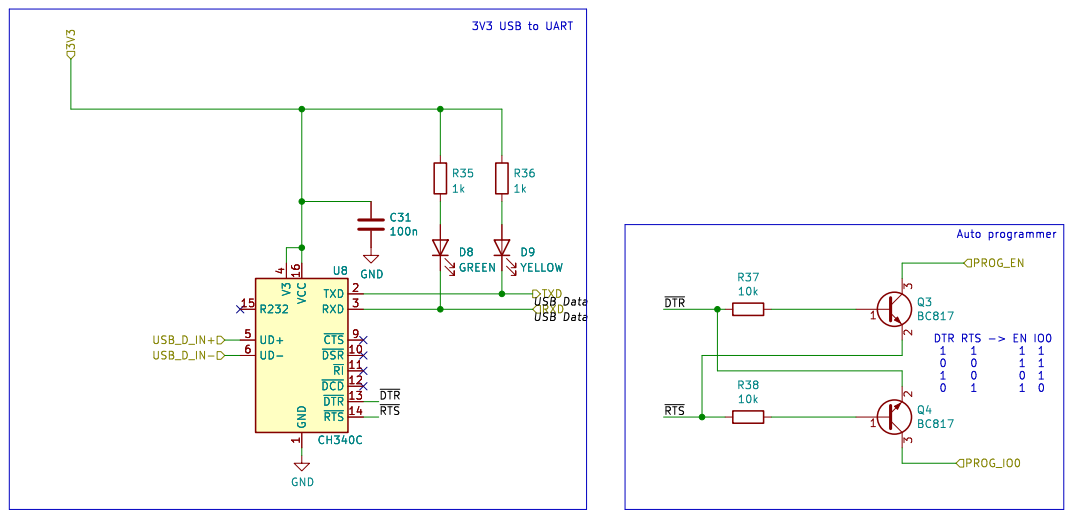
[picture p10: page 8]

4 UD+ 5 UD- 6 ~{CTS}9 D8 GREEN

1 ~{DSR} 10 ~{RI} 11 ~{DCD} 12 ~{DTR} 13 ~{RTS} 14 R232 15 VCC 16 TXD 2 RXD 3 V3

Id: 8/8 Title: Serial Communication

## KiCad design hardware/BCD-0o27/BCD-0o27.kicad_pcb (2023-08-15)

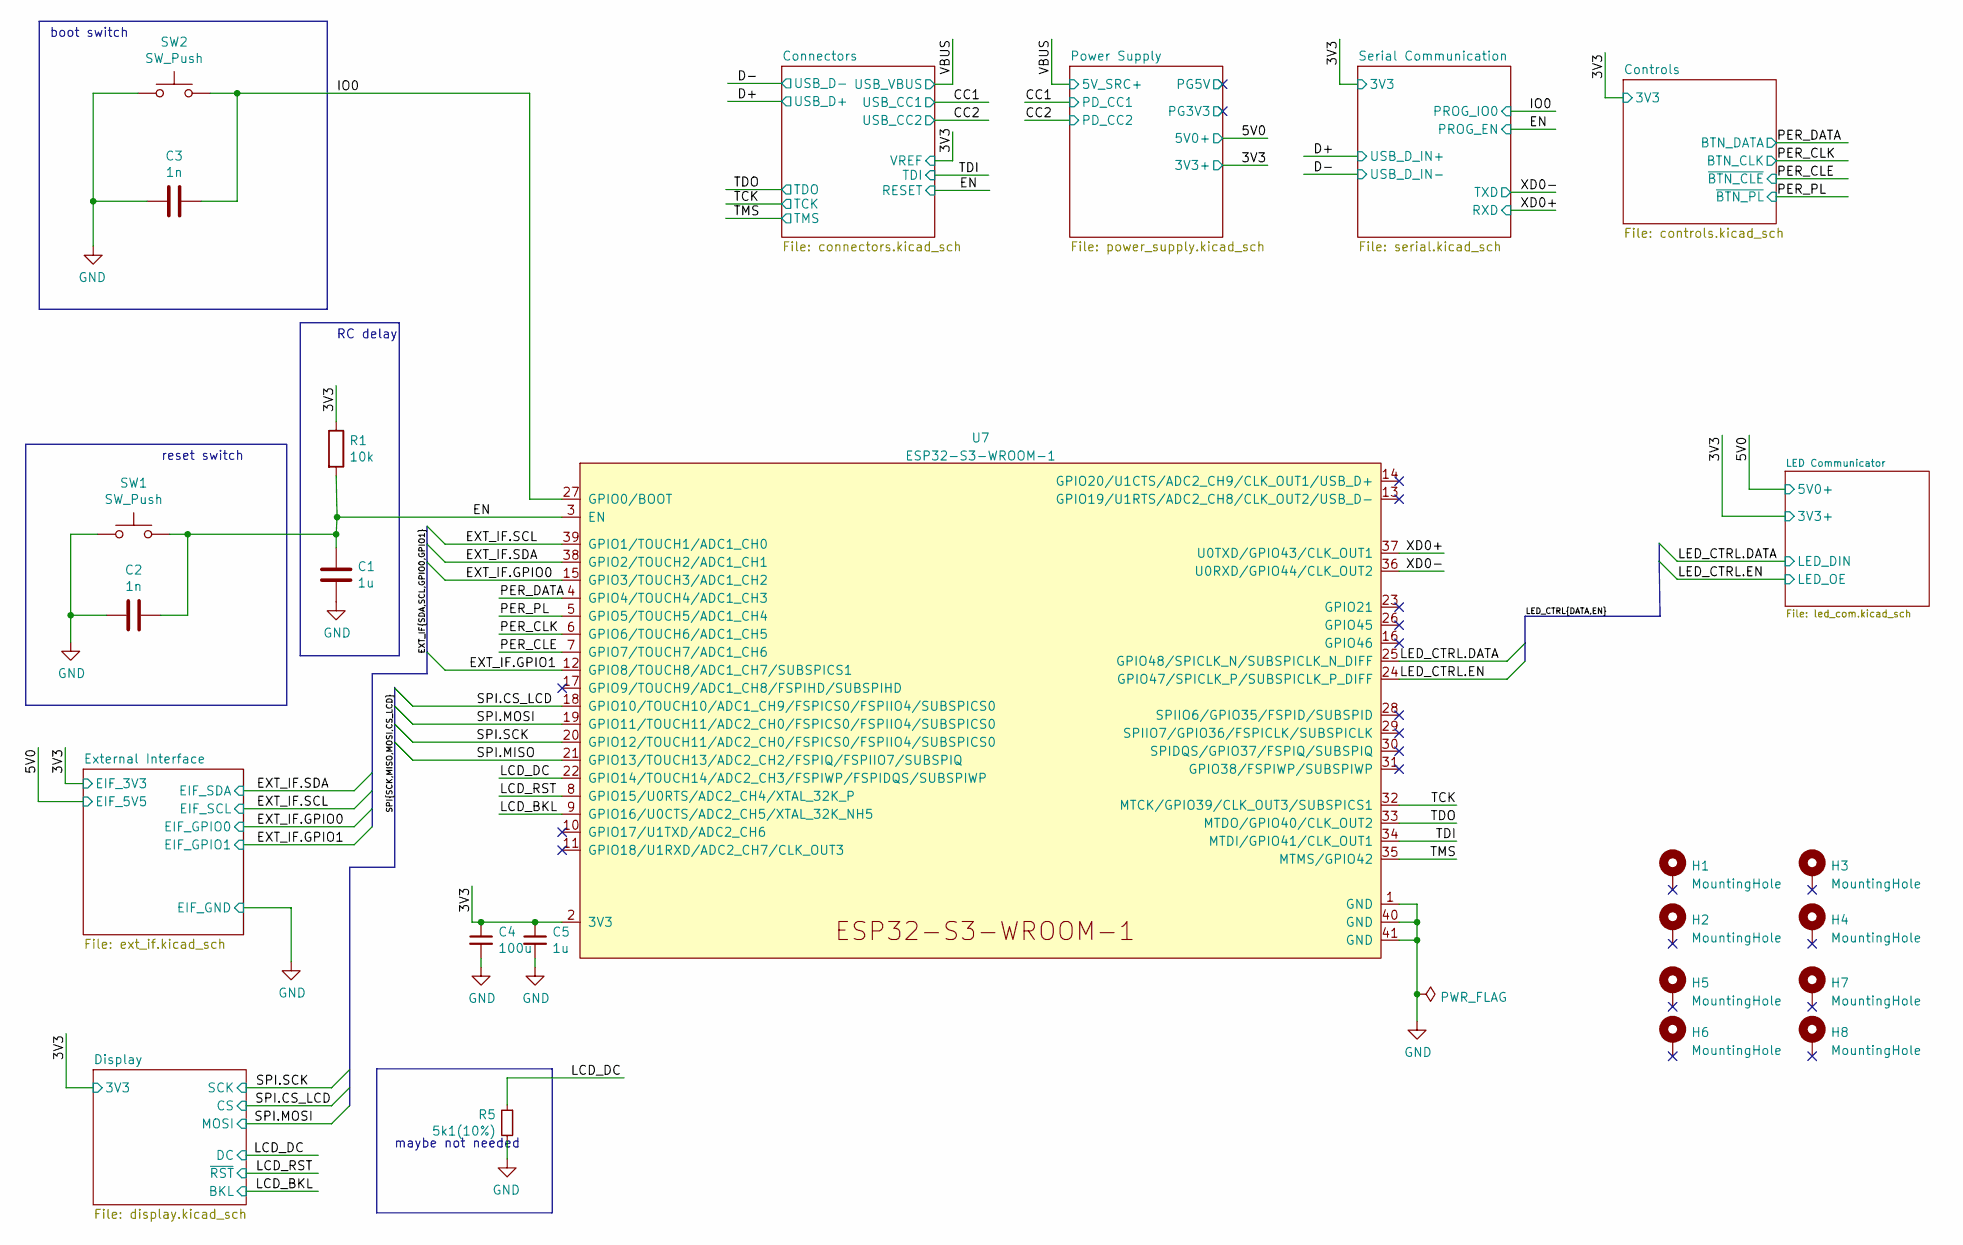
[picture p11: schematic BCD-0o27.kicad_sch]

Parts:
C1, C5: 1u; C_0805_2012Metric; LCSC C28323
C2, C3: 1n; C_0805_2012Metric; LCSC C46653
C4: 100u; C_1206_3216Metric; LCSC C15008
H1, H2, H3, H4, H5, H6, H7, H8: MountingHole; MountingHole_2.2mm_M2_ISO7380_Pad_TopBottom
R1: 10k; R_0805_2012Metric; LCSC C17414
R5: 5k1(10%); R_0603_1608Metric; LCSC C23186
SW1, SW2: SW_Push; XUNPU TS-1087S Tactile Switch; LCSC C455268
U7: ESP32-S3-WROOM-1; LCSC C2913202

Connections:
/3V3: C4.1, C5.1, R1.1, U7.2 (3V3); also elsewhere on the board
/EN: C1.1, C2.1, R1.2, SW1.2, U7.3 (EN); also elsewhere on the board
/EXT_IF.GPIO0: U7.15 (GPIO3/TOUCH3/ADC1_CH2); also elsewhere on the board
/EXT_IF.GPIO1: U7.12 (GPIO8/TOUCH8/ADC1_CH7/SUBSPICS1); also elsewhere on the board
/EXT_IF.SCL: U7.39 (GPIO1/TOUCH1/ADC1_CH0); also elsewhere on the board
/EXT_IF.SDA: U7.38 (GPIO2/TOUCH2/ADC1_CH1); also elsewhere on the board
/IO0: C3.1, SW2.1, U7.27 (GPIO0/BOOT); also elsewhere on the board
/LCD_BKL: U7.9 (GPIO16/U0CTS/ADC2_CH5/XTAL_32K_NH5); also elsewhere on the board
/LCD_DC: R5.1, U7.22 (GPIO14/TOUCH14/ADC2_CH3/FSPIWP/FSPIDQS/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); also elsewhere on the board
/LCD_RST: U7.8 (GPIO15/U0RTS/ADC2_CH4/XTAL_32K_P); also elsewhere on the board
/LED_CTRL.DATA: U7.25 (GPIO48/SPICLK_N/SUBSPICLK_N_DIFF); also elsewhere on the board
/LED_CTRL.EN: U7.24 (GPIO47/SPICLK_P/SUBSPICLK_P_DIFF); also elsewhere on the board
/PER_CLE: U7.7 (GPIO7/TOUCH7/ADC1_CH6); also elsewhere on the board
/PER_CLK: U7.6 (GPIO6/TOUCH6/ADC1_CH5); also elsewhere on the board
/PER_DATA: U7.4 (GPIO4/TOUCH4/ADC1_CH3); also elsewhere on the board
/PER_PL: U7.5 (GPIO5/TOUCH5/ADC1_CH4); also elsewhere on the board
/SPI.CS_LCD: U7.18 (GPIO10/TOUCH10/ADC1_CH9/FSPICS0/FSPIIO4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); also elsewhere on the board
/SPI.MISO: U7.21 (GPIO13/TOUCH13/ADC2_CH2/FSPIQ/FSPIIO7/S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)
/SPI.MOSI: U7.19 (GPIO11/TOUCH11/ADC2_CH0/FSPICS0/FSPIIO4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); also elsewhere on the board
/SPI.SCK: U7.20 (GPIO12/TOUCH11/ADC2_CH0/FSPICS0/FSPIIO4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); also elsewhere on the board
/TCK: U7.32 (MTCK/GPIO39/CLK_OUT3/SUBSPICS1); also elsewhere on the board
/TDI: U7.34 (MTDI/GPIO41/CLK_OUT1); also elsewhere on the board
/TDO: U7.33 (MTDO/GPIO40/CLK_OUT2); also elsewhere on the board
/TMS: U7.35 (MTMS/GPIO42); also elsewhere on the board
/XD0+: U7.37 (U0TXD/GPIO43/CLK_OUT1); also elsewhere on the board
/XD0-: U7.36 (U0RXD/GPIO44/CLK_OUT2); also elsewhere on the board
GND: C1.2, C2.2, C3.2, C4.2, C5.2, R5.2, SW1.1, SW2.2, U7.1 (GND), U7.40 (GND), U7.41 (GND); also elsewhere on the board

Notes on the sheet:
RC delay
maybe not needed
reset switch
boot switch

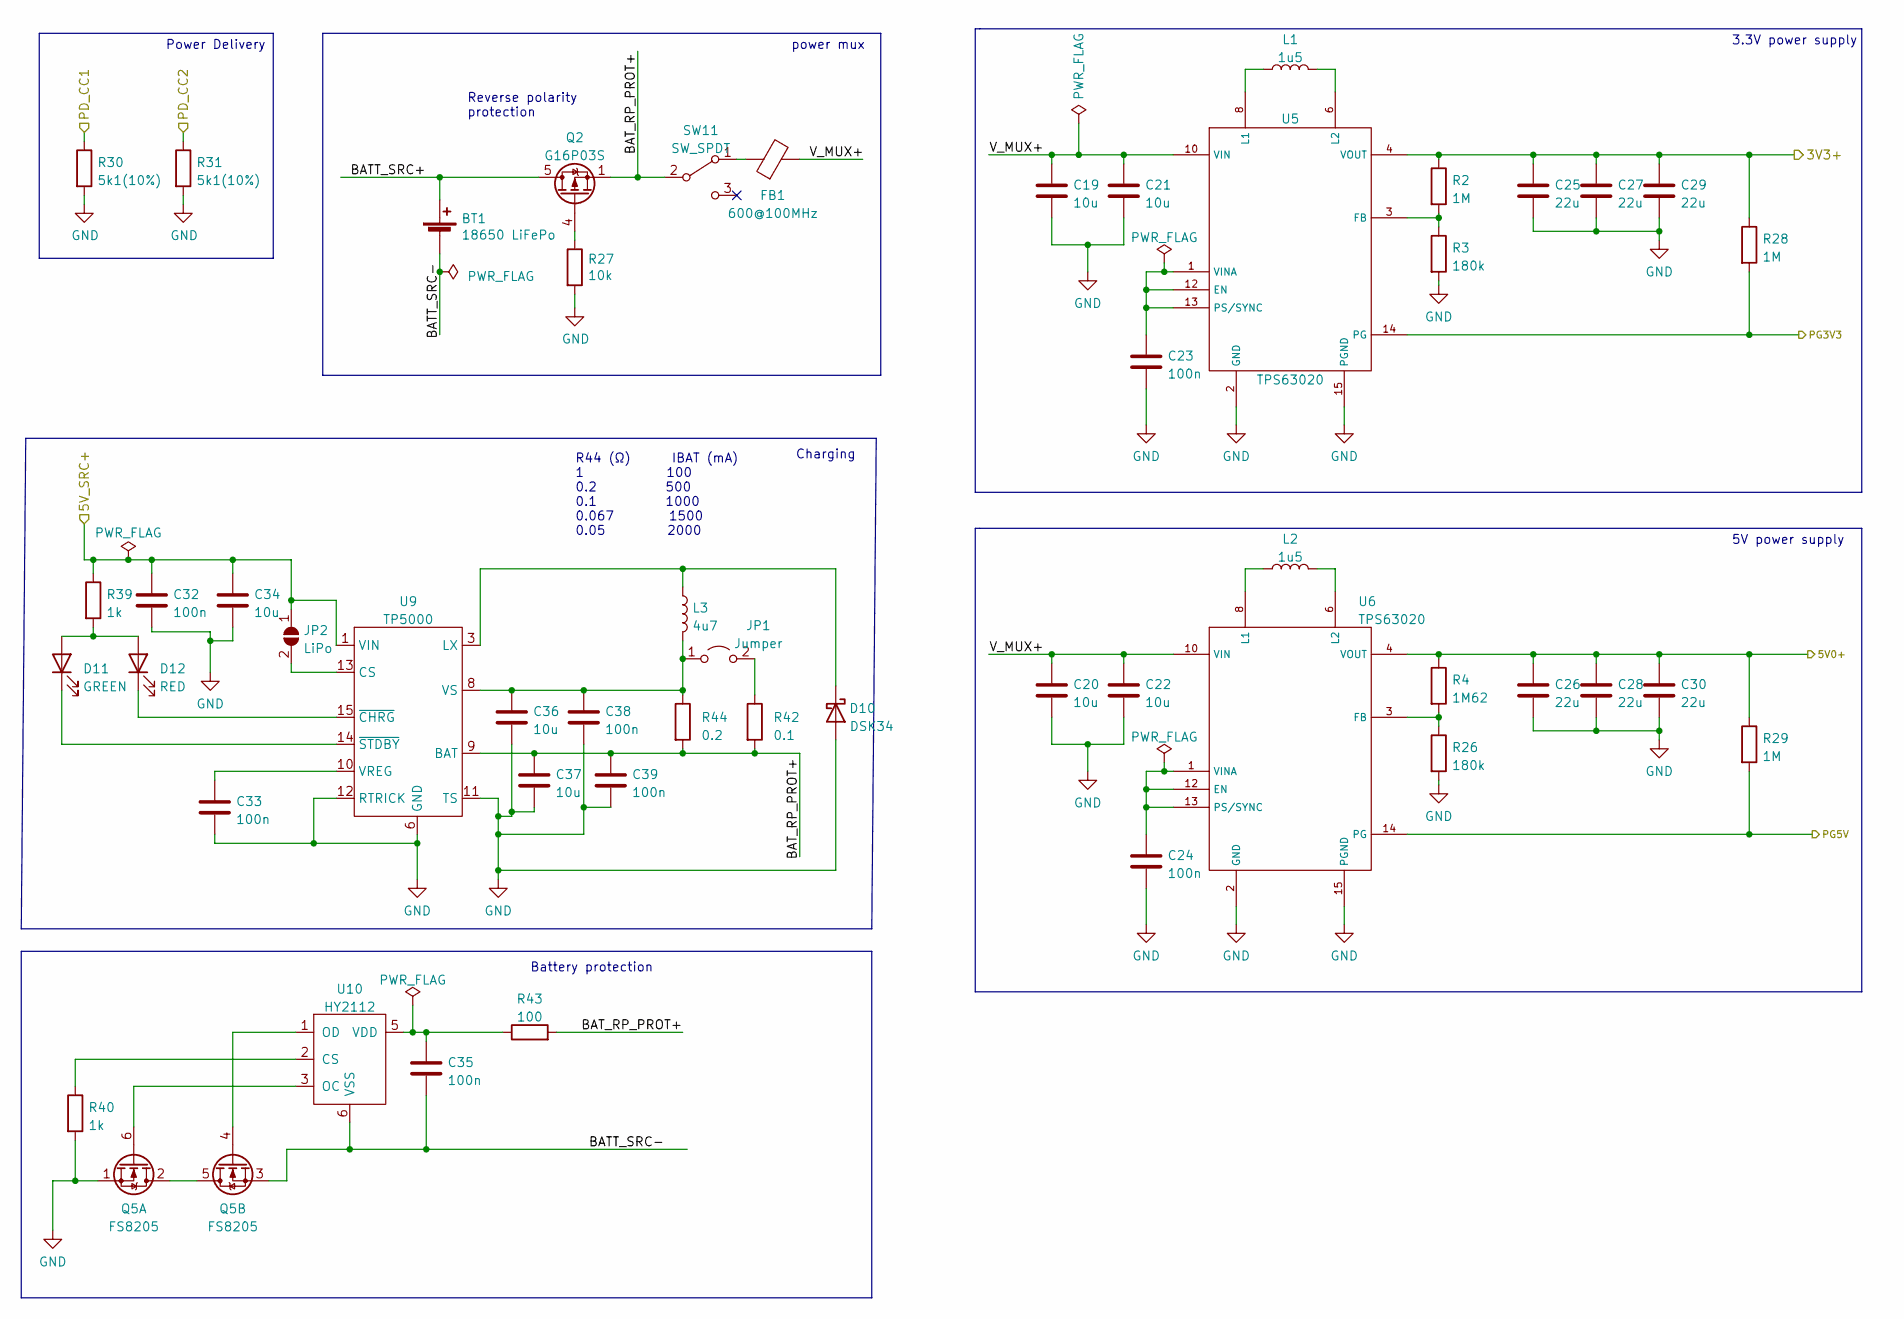
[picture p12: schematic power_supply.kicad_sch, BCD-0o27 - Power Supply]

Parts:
BT1: 18650 LiFePo; BatteryHolder_SMD_SMT_1x18650
C19, C20, C21, C22, C34, C36, C37: 10u; C_0603_1608Metric; LCSC C19702
C23, C24, C32, C33, C35, C38, C39: 100n; C_0603_1608Metric; LCSC C14663
C25, C26, C27, C28, C29, C30: 22u; C_0603_1608Metric; LCSC C59461
D10: DSK34; D_SOD-123; LCSC C908230
D11: GREEN; LED_0805_2012Metric; LCSC C2297
D12: RED; LED_0805_2012Metric; LCSC C84256
FB1: 600@100MHz; L_0805_2012Metric; LCSC C1017
JP1: Jumper; Jumper_P2.54mm_D1.2mm; LCSC C5116481
JP2: LiPo; SolderJumper-2_P1.3mm_Open_RoundedPad1.0x1.5mm
L1, L2: 1u5; L_Murata_FDSD0518; LCSC C2931055
L3: 4u7; L_Sunlord_MWSA0503S; LCSC C351098
Q2: G16P03S; SOP-8_3.9x4.9mm_P1.27mm; LCSC C840046
Q5: FS8205; TSOT-23-6; LCSC C908265
R2, R28, R29: 1M; R_0603_1608Metric; LCSC C22935
R3, R26: 180k; R_0603_1608Metric; LCSC C22827
R4: 1M62; R_0603_1608Metric; LCSC C407540
R27: 10k; R_0805_2012Metric; LCSC C17414
R30, R31: 5k1(10%); R_0603_1608Metric; LCSC C23186
R39, R40: 1k; R_0603_1608Metric; LCSC C21190
R42: 0.1; R_0603_1608Metric; LCSC C5120068
R43: 100; R_0805_2012Metric; LCSC C17408
R44: 0.2; R_0603_1608Metric; LCSC C79773
SW11: SW_SPDT; SS-12M11G3; LCSC C2879832
U5, U6: TPS63020; QFN14-3X4MM; LCSC C15483
U9: TP5000; QFN-16-1EP_4x4mm_P0.65mm_EP2.1x2.1mm; LCSC C51699
U10: HY2112; TSOT-23-6; LCSC C161942

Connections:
/3V3: C25.1, C27.1, C29.1, R2.1, R28.1, U5.4 (VOUT), U5.5 (VOUT); also elsewhere on the board
/5V0: C26.1, C28.1, C30.1, R4.1, R29.1, U6.4 (VOUT), U6.5 (VOUT); also elsewhere on the board
/CC1: R30.1; also elsewhere on the board
/CC2: R31.1; also elsewhere on the board
/Power Supply/BATT_SRC+: BT1.1 (+), Q2.5 (D), Q2.6 (D), Q2.7 (D), Q2.8 (D)
/Power Supply/BATT_SRC-: BT1.2 (-), C35.2, Q5.3 (S2), U10.6 (VSS)
/Power Supply/BAT_RP_PROT+: C37.1, C39.1, Q2.1 (S), Q2.2 (S), Q2.3 (S), R42.2, R43.2, R44.2, SW11.2 (B), U9.9 (BAT)
/Power Supply/PG3V3: R28.2, U5.14 (PG)
/Power Supply/PG5V: R29.2, U6.14 (PG)
/Power Supply/V_MUX+: C19.1, C20.1, C21.1, C22.1, FB1.2, U5.10 (VIN), U5.11 (VIN), U6.10 (VIN), U6.11 (VIN)
/VBUS: C32.1, C34.1, JP2.1 (A), R39.1, U9.1 (VIN), U9.2 (VIN), U9.16 (VIN); also elsewhere on the board
GND: C19.2, C20.2, C21.2, C22.2, C23.2, C24.2, C25.2, C26.2, C27.2, C28.2, C29.2, C30.2, C32.2, C33.2, C34.2, C36.2, C37.2, C38.2, C39.2, D10.2 (A), Q5.1 (S2), R3.2, R26.2, R27.2, R30.2, R31.2, R40.2, U5.2 (GND), U5.15 (PGND), U5.16 (PGND), U5.17 (PGND), U5.18 (PGND), U5.19 (PGND), U5.20 (PGND), U5.21 (PGND), U5.22 (PGND), U5.23 (PGND), U6.2 (GND), U6.15 (PGND), U6.16 (PGND), U6.17 (PGND), U6.18 (PGND), U6.19 (PGND), U6.20 (PGND), U6.21 (PGND), U6.22 (PGND), U6.23 (PGND), U9.6 (GND), U9.7 (GND), U9.11 (TS), U9.12 (RTRICK); also elsewhere on the board
unnamed: C23.1, U5.1 (VINA), U5.12 (EN), U5.13 (PS/SYNC)
unnamed: C24.1, U6.1 (VINA), U6.12 (EN), U6.13 (PS/SYNC)
unnamed: C35.1, R43.1, U10.5 (VDD)
unnamed: D10.1 (K), L3.1, U9.3 (LX), U9.4 (LX), U9.5 (LX)
unnamed: D11.2 (A), D12.2 (A), R39.2
unnamed: D11.1 (K), U9.14 (~STDBY)
unnamed: D12.1 (K), U9.15 (~CHRG)
unnamed: C36.1, C38.1, JP1.1 (A), L3.2, R44.1, U9.8 (VS)
unnamed: JP1.2 (B), R42.1
unnamed: JP2.2 (B), U9.13 (CS)
unnamed: L1.1, U5.8 (L1), U5.9 (L1)
unnamed: L1.2, U5.6 (L2), U5.7 (L2)
unnamed: L2.1, U6.8 (L1), U6.9 (L1)
unnamed: L2.2, U6.6 (L2), U6.7 (L2)
unnamed: Q2.4 (G), R27.1
unnamed: Q5.2 (D12), Q5.5 (D12)
unnamed: Q5.6 (G2), U10.3 (OC)
unnamed: Q5.4 (G2), U10.1 (OD)
unnamed: FB1.1, SW11.1 (A)
unnamed: R2.2, R3.1, U5.3 (FB)
unnamed: R4.2, R26.1, U6.3 (FB)
unnamed: C33.1, U9.10 (VREG)
unnamed: R40.1, U10.2 (CS)

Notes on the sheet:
3.3V power supply
Power Delivery
power mux
Charging
5V power supply
Battery protection
Reverse polarity protection
R44 (Ω) IBAT (mA) 1 100 0.2 500 0.1 1000 0.067 1500 0.05 2000

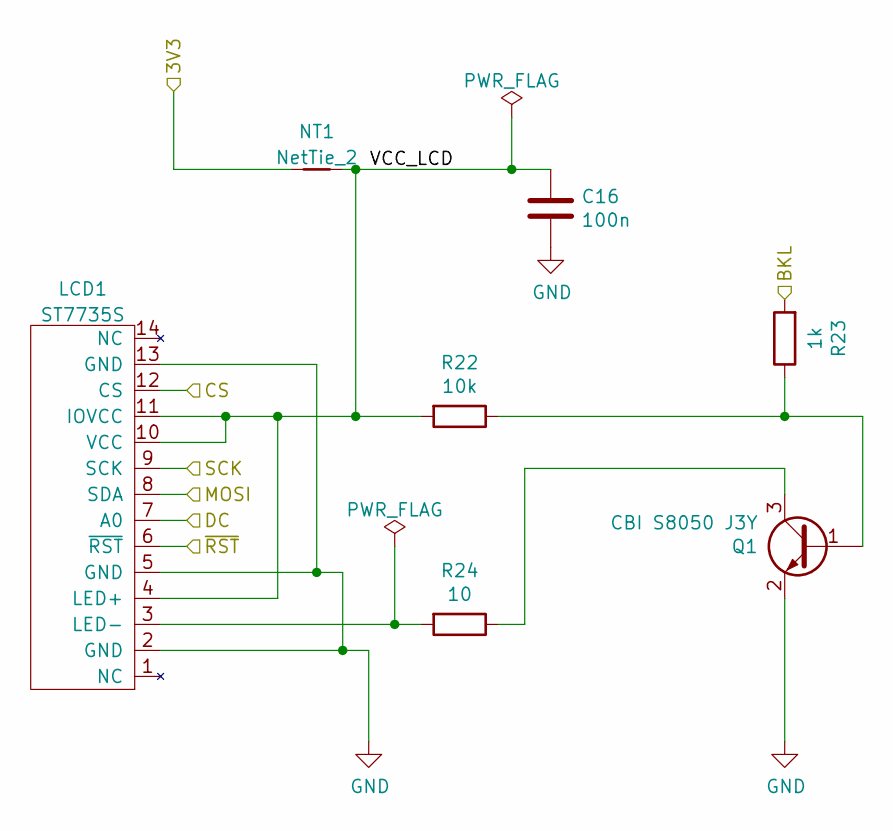
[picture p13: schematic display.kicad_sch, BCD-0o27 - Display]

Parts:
C16: 100n; C_0603_1608Metric; LCSC C14663
LCD1: ST7735S; ST7735S-1.8-Inch-128x160px-tft
NT1: NetTie_2; NetTie-2_SMD_Pad0.5mm
Q1: CBI S8050 J3Y; SOT-23; LCSC C2146
R22: 10k; R_0805_2012Metric; LCSC C17414
R23: 1k; R_0603_1608Metric; LCSC C21190
R24: 10; R_0805_2012Metric; LCSC C17415

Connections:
/3V3: NT1.1; also elsewhere on the board
/Display/VCC_LCD: C16.1, LCD1.4 (LED+), LCD1.10 (VCC), LCD1.11 (IOVCC), NT1.2, R22.2
/LCD_BKL: R23.2; also elsewhere on the board
/LCD_DC: LCD1.7 (A0); also elsewhere on the board
/LCD_RST: LCD1.6 (~RST); also elsewhere on the board
/SPI.CS_LCD: LCD1.12 (CS); also elsewhere on the board
/SPI.MOSI: LCD1.8 (SDA); also elsewhere on the board
/SPI.SCK: LCD1.9 (SCK); also elsewhere on the board
GND: C16.2, LCD1.2 (GND), LCD1.5 (GND), LCD1.13 (GND), Q1.2 (E); also elsewhere on the board
unnamed: LCD1.3 (LED-), R24.2
unnamed: Q1.1 (B), R22.1, R23.1
unnamed: Q1.3 (C), R24.1

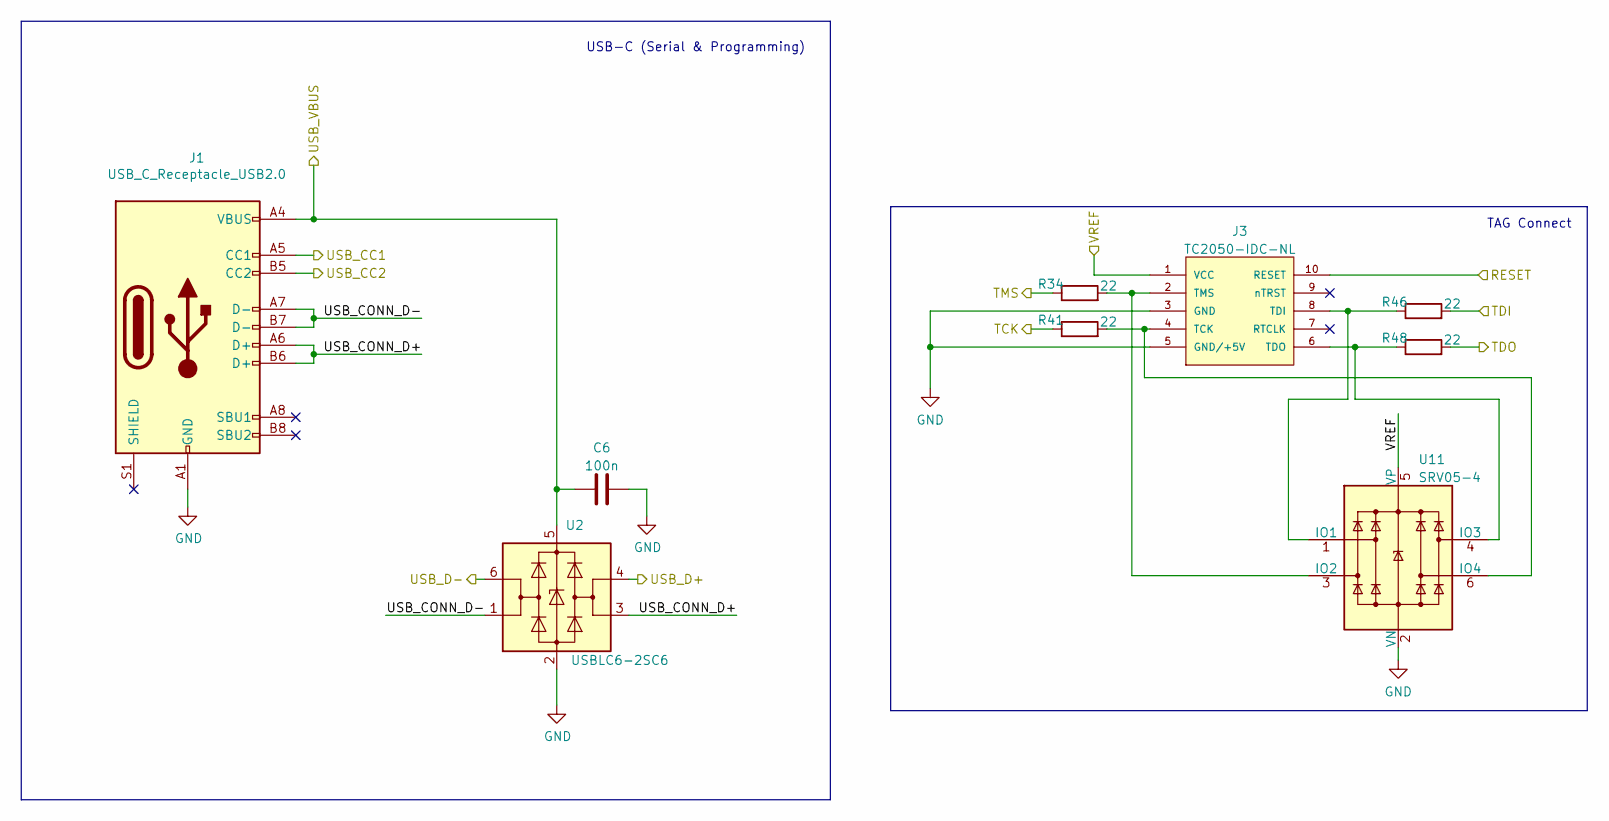
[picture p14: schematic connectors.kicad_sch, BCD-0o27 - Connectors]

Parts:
C6: 100n; C_0603_1608Metric; LCSC C14663
J1: USB_C_Receptacle_USB2.0; USB_C_Receptacle_HRO_TYPE-C-31-M-12; LCSC C165948
J3: TC2050-IDC-NL; TAG-CONNECT_TC2050-IDC-NL; PARTREV A
R34, R41, R46, R48: 22; R_0603_1608Metric; LCSC C23345
U2: USBLC6-2SC6; SOT-23-6; LCSC C2687116
U11: SRV05-4; SOT-23-6; LCSC C558418

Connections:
/3V3: J3.1 (VCC), U11.5 (VP); also elsewhere on the board
/CC1: J1.A5 (CC1); also elsewhere on the board
/CC2: J1.B5 (CC2); also elsewhere on the board
/Connectors/USB_CONN_D+: J1.A6 (D+), J1.B6 (D+), U2.3 (I/O2)
/Connectors/USB_CONN_D-: J1.A7 (D-), J1.B7 (D-), U2.1 (I/O1)
/D+: U2.4 (I/O2); also elsewhere on the board
/D-: U2.6 (I/O1); also elsewhere on the board
/EN: J3.10 (RESET); also elsewhere on the board
/TCK: R41.1; also elsewhere on the board
/TDI: R46.2; also elsewhere on the board
/TDO: R48.2; also elsewhere on the board
/TMS: R34.1; also elsewhere on the board
/VBUS: C6.1, J1.A4 (VBUS), J1.A9 (VBUS), J1.B4 (VBUS), J1.B9 (VBUS), U2.5 (VBUS); also elsewhere on the board
GND: C6.2, J1.A1 (GND), J1.A12 (GND), J1.B1 (GND), J1.B12 (GND), J3.3 (GND), J3.5 (GND/+5V), U2.2 (GND), U11.2 (VN); also elsewhere on the board
unnamed: J3.4 (TCK), R41.2, U11.6 (IO4)
unnamed: J3.8 (TDI), R46.1, U11.1 (IO1)
unnamed: J3.6 (TDO), R48.1, U11.4 (IO3)
unnamed: J3.2 (TMS), R34.2, U11.3 (IO2)

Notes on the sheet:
TAG Connect
USB-C (Serial & Programming)

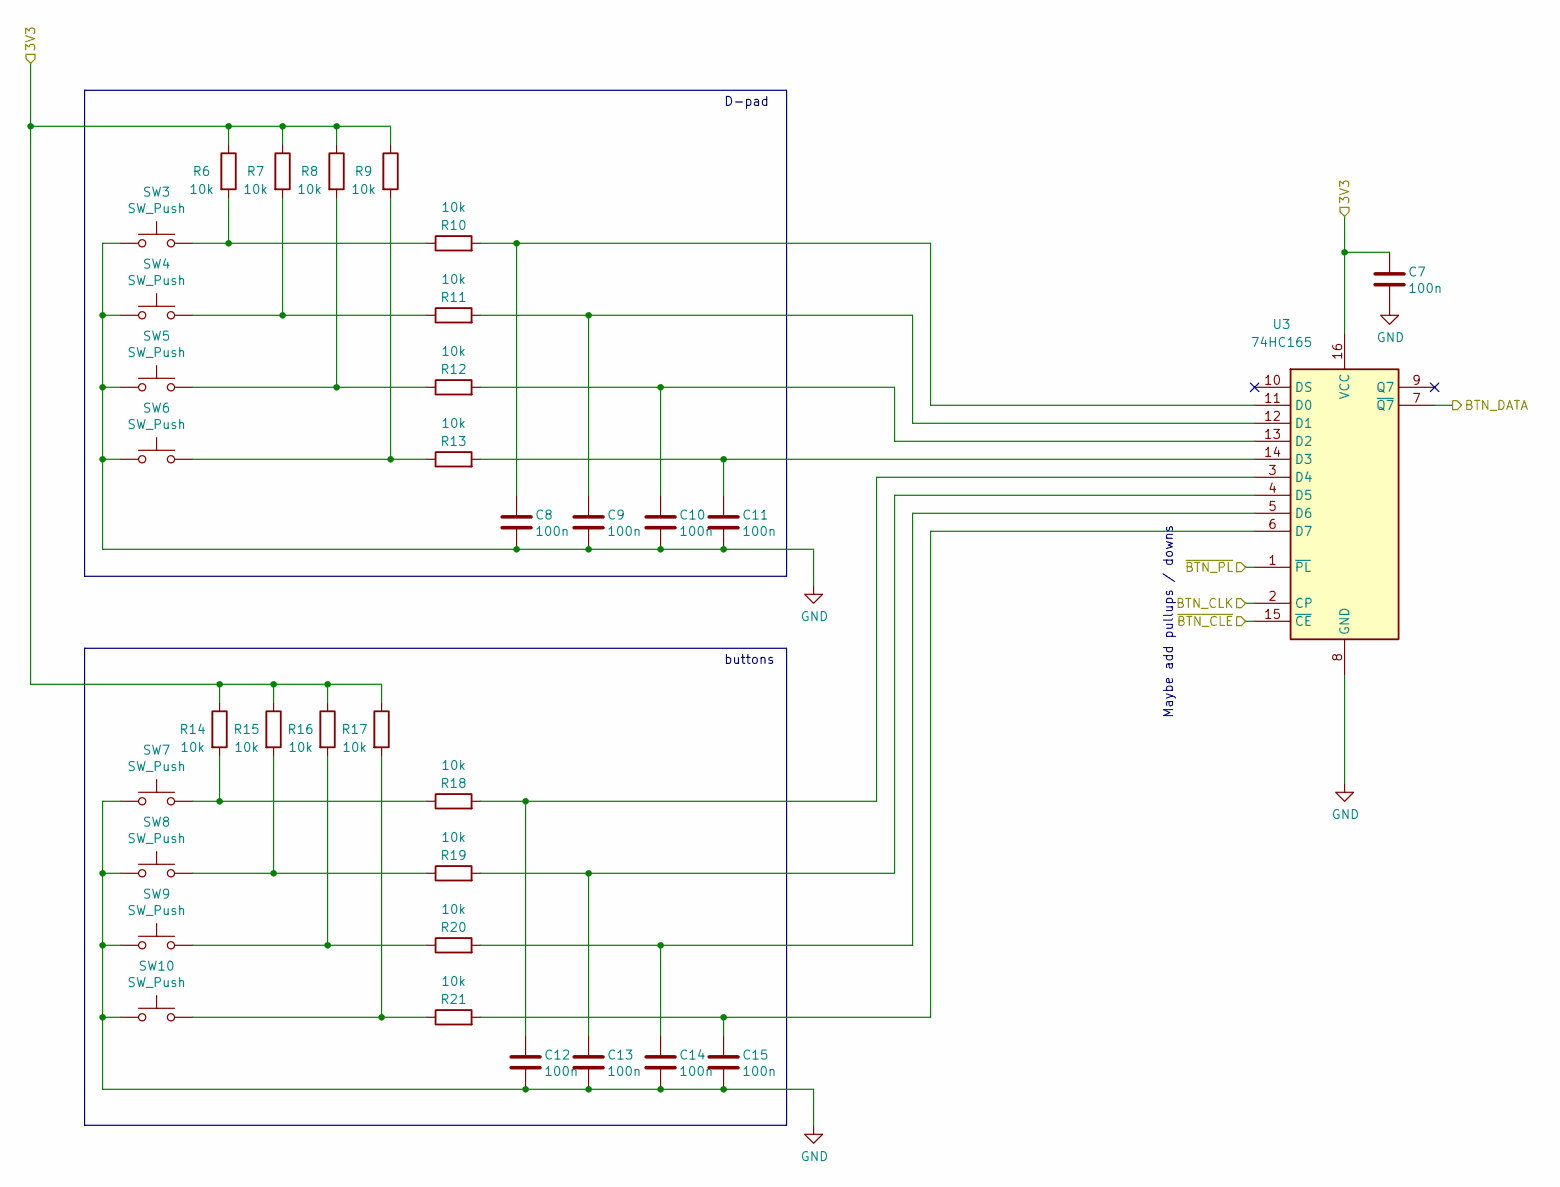
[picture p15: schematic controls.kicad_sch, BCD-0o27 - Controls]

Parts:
C7, C8, C9, C10, C11, C12, C13, C14, C15: 100n; C_0603_1608Metric; LCSC C14663
R6, R7, R8, R9, R10, R11, R12, R13, R14, R15, R16, R17, R18, R19, R20, R21: 10k; R_0805_2012Metric; LCSC C17414
SW3, SW4, SW5, SW6, SW7, SW8, SW9, SW10: SW_Push; XUNPU TS-1087S Tactile Switch; LCSC C455268
U3: 74HC165; SOIC-16_3.9x9.9mm_P1.27mm; LCSC C470977

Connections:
/3V3: C7.1, R6.1, R7.1, R8.1, R9.1, R14.1, R15.1, R16.1, R17.1, U3.16 (VCC); also elsewhere on the board
/PER_CLE: U3.15 (~CE); also elsewhere on the board
/PER_CLK: U3.2 (CP); also elsewhere on the board
/PER_DATA: U3.7 (~Q7); also elsewhere on the board
/PER_PL: U3.1 (~PL); also elsewhere on the board
GND: C7.2, C8.2, C9.2, C10.2, C11.2, C12.2, C13.2, C14.2, C15.2, SW3.1, SW4.1, SW5.1, SW6.1, SW7.1, SW8.1, SW9.1, SW10.1, U3.8 (GND); also elsewhere on the board
unnamed: R6.2, R10.1, SW3.2
unnamed: R7.2, R11.1, SW4.2
unnamed: R8.2, R12.1, SW5.2
unnamed: R9.2, R13.1, SW6.2
unnamed: R14.2, R18.1, SW7.2
unnamed: R15.2, R19.1, SW8.2
unnamed: R16.2, R20.1, SW9.2
unnamed: R17.2, R21.1, SW10.2
unnamed: C8.1, R10.2, U3.11 (D0)
unnamed: C9.1, R11.2, U3.12 (D1)
unnamed: C10.1, R12.2, U3.13 (D2)
unnamed: C11.1, R13.2, U3.14 (D3)
unnamed: C12.1, R18.2, U3.3 (D4)
unnamed: C13.1, R19.2, U3.4 (D5)
unnamed: C14.1, R20.2, U3.5 (D6)
unnamed: C15.1, R21.2, U3.6 (D7)

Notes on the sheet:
Maybe add pullups / downs
D-pad
buttons

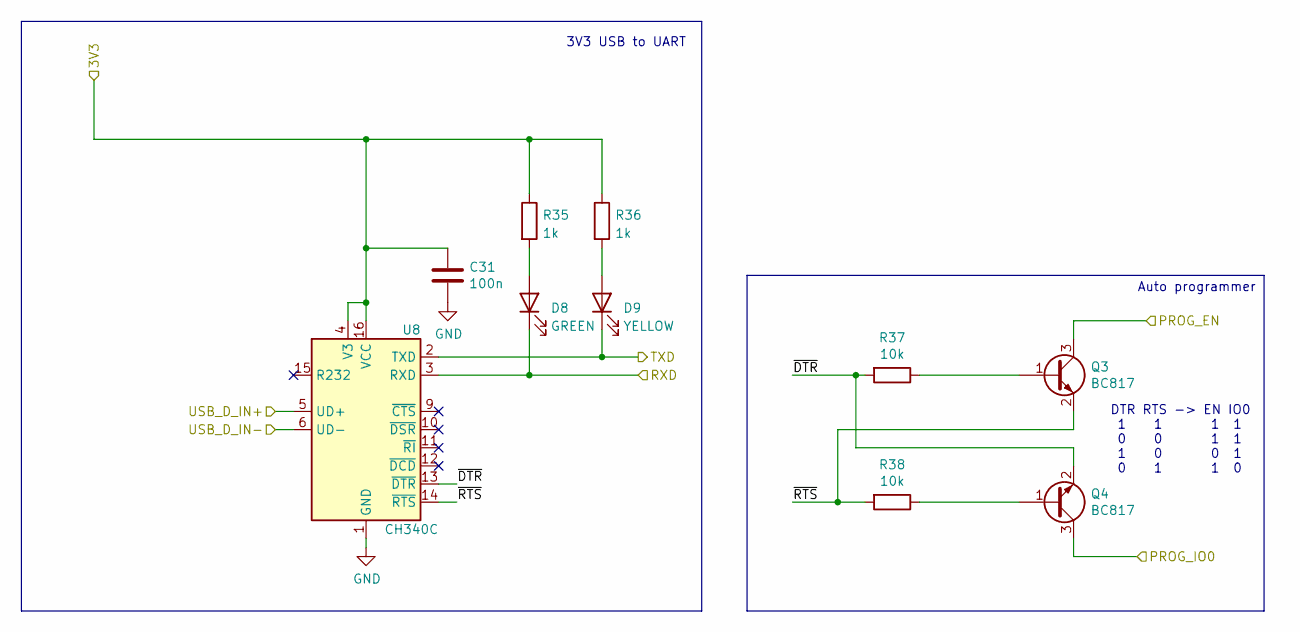
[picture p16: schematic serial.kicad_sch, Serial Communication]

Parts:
C31: 100n; C_0603_1608Metric; LCSC C14663
D8: GREEN; LED_0805_2012Metric; LCSC C2297
D9: YELLOW; LED_0805_2012Metric; LCSC C2296
Q3, Q4: BC817; SOT-23; LCSC C475629
R35, R36: 1k; R_0603_1608Metric; LCSC C21190
R37, R38: 10k; R_0805_2012Metric; LCSC C17414
U8: CH340C; SOIC-16_3.9x9.9mm_P1.27mm; LCSC C84681

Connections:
/3V3: C31.1, R35.1, R36.1, U8.4 (V3), U8.16 (VCC); also elsewhere on the board
/D+: U8.5 (UD+); also elsewhere on the board
/D-: U8.6 (UD-); also elsewhere on the board
/EN: Q3.3 (C); also elsewhere on the board
/IO0: Q4.3 (C); also elsewhere on the board
/Serial Communication/~DTR: Q4.2 (E), R37.2, U8.13 (~DTR)
/Serial Communication/~RTS: Q3.2 (E), R38.2, U8.14 (~RTS)
/XD0+: D8.1 (K), U8.3 (RXD); also elsewhere on the board
/XD0-: D9.1 (K), U8.2 (TXD); also elsewhere on the board
GND: C31.2, U8.1 (GND); also elsewhere on the board
unnamed: D8.2 (A), R35.2
unnamed: D9.2 (A), R36.2
unnamed: Q3.1 (B), R37.1
unnamed: Q4.1 (B), R38.1

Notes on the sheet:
Auto programmer
3V3 USB to UART
DTR RTS -> EN IO0 1 1 1 1 0 0 1 1 1 0 0 1 0 1 1 0

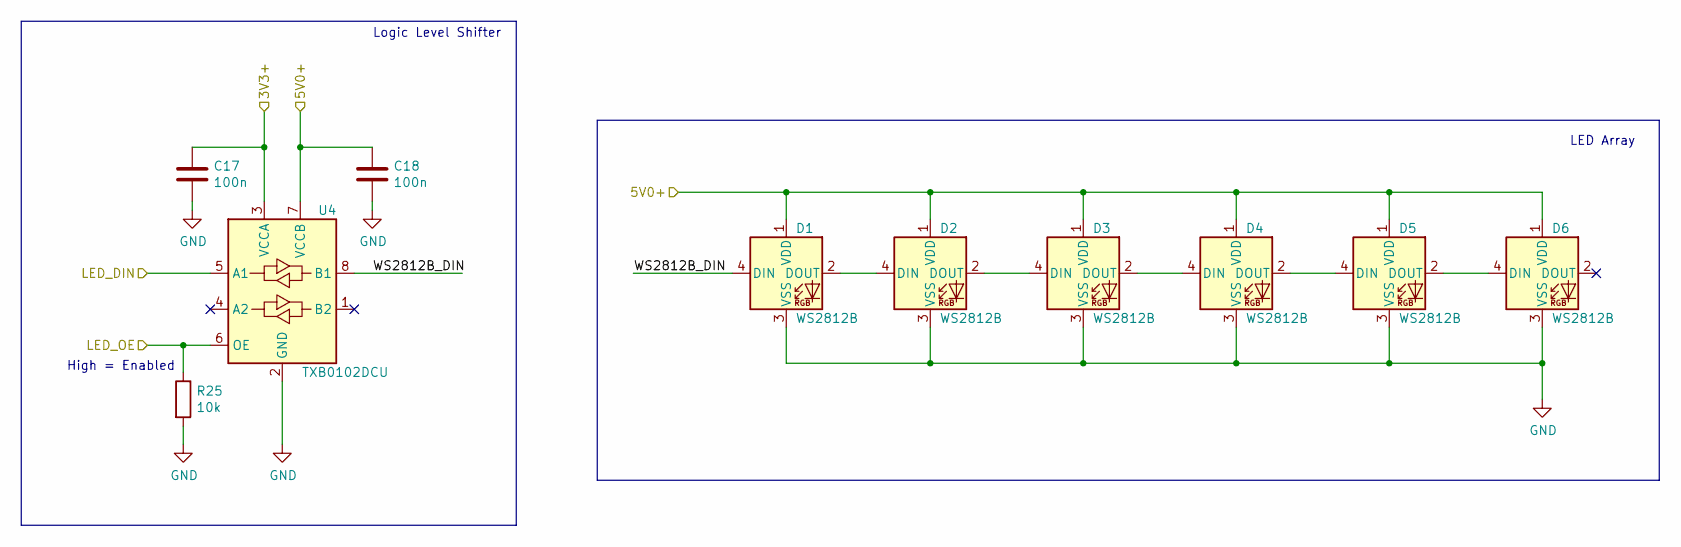
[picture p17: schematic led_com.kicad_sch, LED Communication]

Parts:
C17, C18: 100n; C_0603_1608Metric; LCSC C14663
D1, D2, D3, D4, D5, D6: WS2812B; LED_WS2812B_PLCC4_5.0x5.0mm_P3.2mm; LCSC C2761795
R25: 10k; R_0805_2012Metric; LCSC C17414
U4: TXB0102DCU; VSSOP-8_2.4x2.1mm_P0.5mm; LCSC C60709

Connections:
/3V3: C17.1, U4.3 (VCCA); also elsewhere on the board
/5V0: C18.1, D1.1 (VDD), D2.1 (VDD), D3.1 (VDD), D4.1 (VDD), D5.1 (VDD), D6.1 (VDD), U4.7 (VCCB); also elsewhere on the board
/LED Communicator/WS2812B_DIN: D1.4 (DIN), U4.8 (B1)
/LED_CTRL.DATA: U4.5 (A1); also elsewhere on the board
/LED_CTRL.EN: R25.1, U4.6 (OE); also elsewhere on the board
GND: C17.2, C18.2, D1.3 (VSS), D2.3 (VSS), D3.3 (VSS), D4.3 (VSS), D5.3 (VSS), D6.3 (VSS), R25.2, U4.2 (GND); also elsewhere on the board
unnamed: D1.2 (DOUT), D2.4 (DIN)
unnamed: D2.2 (DOUT), D3.4 (DIN)
unnamed: D3.2 (DOUT), D4.4 (DIN)
unnamed: D4.2 (DOUT), D5.4 (DIN)
unnamed: D5.2 (DOUT), D6.4 (DIN)

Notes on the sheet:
High = Enabled
LED Array
Logic Level Shifter

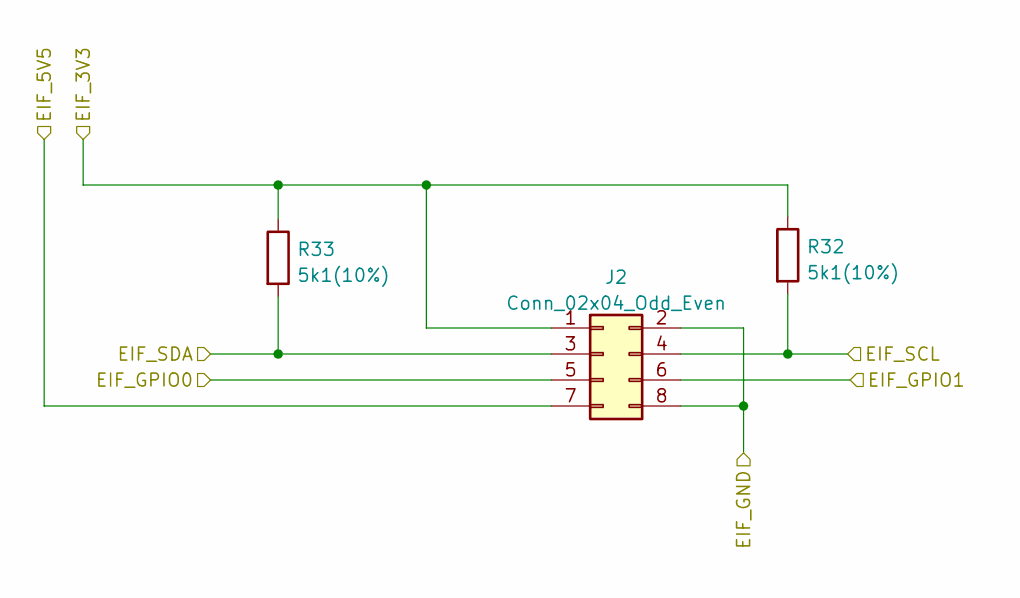
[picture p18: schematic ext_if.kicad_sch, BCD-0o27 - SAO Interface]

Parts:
J2: Conn_02x04_Odd_Even; PinSocket_2x04_P2.54mm_Vertical; LCSC C2977588
R32, R33: 5k1(10%); R_0603_1608Metric; LCSC C23186

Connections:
/3V3: J2.1, R32.1, R33.1; also elsewhere on the board
/5V0: J2.7; also elsewhere on the board
/EXT_IF.GPIO0: J2.5; also elsewhere on the board
/EXT_IF.GPIO1: J2.6; also elsewhere on the board
/EXT_IF.SCL: J2.4, R32.2; also elsewhere on the board
/EXT_IF.SDA: J2.3, R33.2; also elsewhere on the board
GND: J2.2, J2.8; also elsewhere on the board

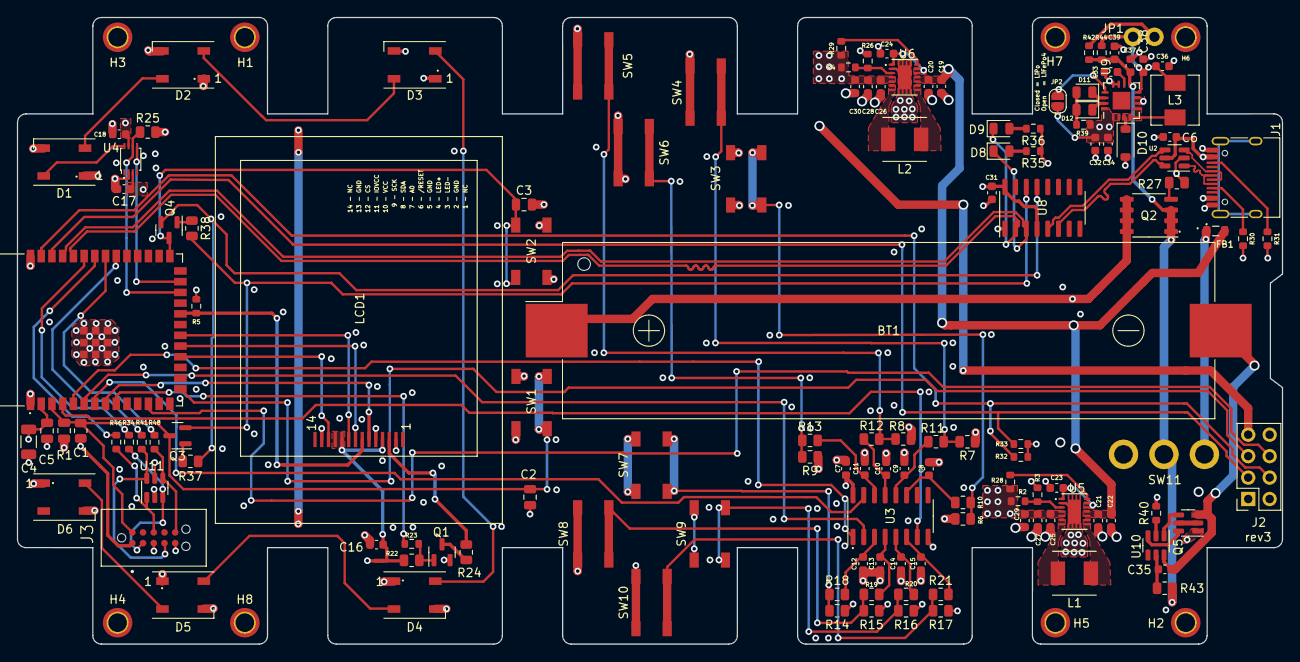
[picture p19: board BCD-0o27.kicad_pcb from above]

Board: 4 copper layers, 149.9 x 74.2 mm, 142 parts (0 on the bottom side), 99 nets.

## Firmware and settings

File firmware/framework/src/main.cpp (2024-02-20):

#include "main.hpp"

/****************************************************************
 * Main App
 ****************************************************************/
Main App;

void Main::run(void) {
#ifdef CONFIG_DEBUG_STACK
	UBaseType_t uxHighWaterMark;

	/* Inspect our own high water mark on entering the task. */
	uxHighWaterMark = uxTaskGetStackHighWaterMark( NULL );
	ESP_LOGD(TAG_STACK, "Main:run(): High watermark for stack at start is: %d", uxHighWaterMark);
#endif

	// --> You might want to put you logic below here. Unless you know what you
	//     are doing, you do not need to change any other code of the framwork
	//     outside this top and the bottom marker. Except of course the modules
	//     you add under ../modules and console commands you add under ../console
	//     and the adaption in the header file for include files.

	
	// 0 Firmware functionality preparations
	//
	// If your firmware uses objects like menus, special symbols or sprites 
	// etc... this is a good place to set them up.
	
	// <--- Set up objects etc... used throughout firmware below -->

	// <--- Set up objects etc... used throughout firmware above -->

	
	// 1 Register the console commands
	//
	// First we register the commands for the console. While this can basically
	// be done any time, it does not hurt to make them available early in the 
	// programm.
	// It is recommended to guard the command registration with 
	// if(hwcap.console) to avoid errors if console initialisation failed or
	// the cyberdeck variant doew not support a console.
	if(bcd_sys.consoleSupport()) {
		// <--- Register console commands below -->
		// Make sure to also include needed headers in main.hpp

		// <--- Register console commands above -->
	}
	

	// 2 Register the modules
	//
	// Now is usually a good time to register modules. Normally, modules are 
	// registered in a menu such that they can be selected for execution. In
	// some cases however, a command may also be just exectured or even be used
	// only later in special cases.

	// <--- Register modules below -->
	// Make sure to also include needed headers in main.hpp

	// <--- Register modules above -->


	// 3 Set up phase
	//
	// Everything that needs to be set up or run before moving into the main 
	// loop can be put here.
	
	// <--- Put setup code and one time acitons below -->	

	
	//screenSize = lcd.dimensions();
    //screenBuffer = (uint8_t *)malloc(bmp_type::sizeof_buffer(screenSize)*sizeof(uint8_t));
	//
    //if(screenBuffer == nullptr)
    //    ESP_LOGW("Tetris", "Not buffering display: Not enough free memory.");
    //else 
	//{
    //    screen = (bmp_type *)malloc(sizeof(bmp_type));
	//
    //    if(screen == nullptr) 
	//	{
    //        ESP_LOGW("Tetris", "Not buffering display: Not enough free memory.");
    //        free(screenBuffer);
    //        screenBuffer = nullptr;
    //    } 
	//	else 		
    //        screen = new (screen) bmp_type(screenSize, screenBuffer);
    //}
	

	// --- Put setup code and one time acitons above -->


	// 4 Implement your main loop
	//
	// A programm for the cyberdeck should never return. In the main loop you
	// usually process all user input and actions.

	// <--- Implement your main loop below -->
	// Make sure your main loop never terminates.
	
	GameState gameState = GameState::Start;
	int exitGame = false;
	while (!exitGame)
	{
		switch(gameState)
		{
		case GameState::Start:			
			gameState = runStartScreen();
			break;
		case GameState::Running:		
			gameState = runGameScreen();
			break;
		case GameState::Paused:
			gameState = runPauseScreen();
			break;
		case GameState::End:		
			gameState = runEndScreen();
			break;
		case GameState::Lost:
			gameState = runLostScreen();
			break;
		case GameState::Exit:
			exitGame = true;
			break;
		}
	}	
	// <--- Implement your main loop above -->
	
	// --> You might want to ensure your code is complete above this line and the code
	//     below this line is never reached, unless you know what you are doing.

	ESP_LOGD(TAG_FS, "Exiting app");


	// Guard
	//
	// This code should never be reached. It is here purely as a guard in case
	// there is a programming error that terminates the loop above. This guard
	// will let the badge print stack debugging information every 10 seconds,
	// if stack debugging is enabled. Otherwise it will just loop forever, doing
	// nothing. Other threads may though still be active (eg. console or leds)
	while(true) {
		vTaskDelay(pdMS_TO_TICKS(10000));
#ifdef CONFIG_DEBUG_STACK
		/* Inspect our own high water mark on entering the task. */
		uxHighWaterMark = uxTaskGetStackHighWaterMark( NULL );
		ESP_LOGD(TAG_STACK, "Main:run(): High watermark for stack in idle guard is: %d", uxHighWaterMark);
#endif //CONFIG_DEBUG_STACK  
	};
}


/**
 * @brief The setup function for the badge
 * 
 * This function initilises all the hardware on the badge and does other
 * preparatory tasks, such as connecting to WiFi. 
 * 
 * We start by loading the minimal drivers to display the conference logo and
 * some loading sequence. This requires the led drivers, display drivers and the
 * led drivers to be set up. After displaying the loading screen, we initialise
 * the rest of the hardware and complete software setup.
 * 
 * Sequence:
 *      0. Leds
 *      1. Display setup
 *      2. Filesystem setup:
 *          - SPIFFS 
 *          - NVS
 *      3. Controller (push buttons)
 *      4. Console
 *      5. WiFi
 * 
 * Note: When setting the leds we do not check for the scheduler state. We get
 *          away with this as we just initialised the leds and we know that 
 *          the scheduler is stopped. Also we know that there is no other thread
 *          that can start the scheduler at this point in time.
 */
void Main::setup(void) {
#ifdef CONFIG_DEBUG_STACK
	UBaseType_t uxHighWaterMark;

	/* Inspect our own high water mark on entering the task. */
	uxHighWaterMark = uxTaskGetStackHighWaterMark( NULL );
	ESP_LOGD(TAG_STACK, "Main:setup(): High watermark for stack at start is:"
		" %d", uxHighWaterMark);
#endif

	// Indicates which driver cluster we are initialising
	uint8_t item_number = 0;

#ifdef CONFIG_LED_IF_SUPPORT
	// LED colors we us throughout the routing
	rgbLEDPixel critical_fail = {
		.red = 0x0F,
		.green = 0x00,
		.blue = 0x00
	};

	rgbLEDPixel fail = {
		.red = 0x0F,
		.green = 0x0F,
		.blue = 0x00
	};

	rgbLEDPixel ok = {
		.red = 0x00,
		.green = 0x0F,
		.blue = 0x00
	};

	rgbLEDPixel clear = {
		.red = 0x00,
		.green = 0x00,
		.blue = 0x00
	};

	// Led state to indicate a fatal error.
	ledStates led_fatal_error;
	for(int i = 0; i < LED_IF_NUM_LED; i++) {
		led_fatal_error.led[i] = critical_fail;      
	}
#endif //CONFIG_LED_IF_SUPPORT

#ifdef CONFIG_DISPLAY_SUPPORT

	// Bootup messages for display
	const font &font = bcd_default_font_FON;;
	const char *bootup_title = "BCD-0o27 booting...";
	const char *bootup_led_msg = "Init LEDs";
	const char *bootup_display_msg = "Init display";
	const char *bootup_fs_msg = "Init filesys";
	const char *bootup_controller_msg = "Init controller";
	const char *bootup_uart_msg = "Init UART";
	const char *bootup_wifi_msg = "Init wifi";
	const char *fail_msg = "FAIL";
	const char *ok_msg = "  OK";

	// Areas on boot screen
	rect16 bootup_title_area(0,0,lcd.width, 2 * font.height());
	rect16 bootup_msg_area(0, bootup_title_area.y2, 
		lcd.width - font.average_width() * 5, bootup_title_area.y2 + font.height());
	rect16 bootup_status_area(bootup_msg_area.x2 + font.average_width(), 
		bootup_msg_area.y1, lcd.width, bootup_msg_area.y2);
#endif //CONFIG_DIAPLAY_SUPPORT

	// 0. Setup LEDs
	//
	// First we try to set up the leds. (We will use the leds to display bootup
	// status.)
	item_number = 0;
#ifdef CONFIG_LED_IF_SUPPORT
	led_err_t led_error = led.getStatus();

	if(led_error != LED_OK) {
		ESP_LOGV(TAG_LED_DRIVER, "Driver in error state (E:0x%x):"
			" Resetting...", led_error);
		led_error = led.reset();
	} 

	if(led_error != LED_OK) {
		//hwcap.led = false;
		bcd_sys.setLedSupport(false);
		ESP_LOGE(TAG_LED_DRIVER, "Could not configure leds. Running without"
			" led support. (E:0x%x)", led_error);
	} else {
		// Clear out all the leds
		ledStates clearLeds;
		for(int i = 0; i < LED_IF_NUM_LED; i++) {
			clearLeds.led[i] = clear;
		}
		led_error = led.setLeds(clearLeds);
		vTaskDelay(pdMS_TO_TICKS(500));                                         //Give the rmt driver some time TODO - 200ms?

		// Now switch first led to green to show successful led setup
		led_error = led.setLed(0, ok);
		vTaskDelay(pdMS_TO_TICKS(500));                                         //Let us enjoy the led 500ms

		if(led_error != LED_OK) {
			ESP_LOGW(TAG_LED_DRIVER, "setLED failed (0x%x)", led_error);
			led_error = LED_OK;                                                 // needed to not display init error
		}
	}
#endif //CONFIG_LED_IF_SUPPORT

#ifdef CONFIG_DISPLAY_SUPPORT
	// 1. Display setup 
	// 
	// If the badge supports a display we initialise it here and clear the 
	// screen.
	item_number++;
	if(!bcd_sys.getSpiHost().initialized()) {
		ESP_LOGE(TAG_DISPLAY, "SPI host initialization error. Halting...\r\n");
#ifdef CONFIG_LED_IF_SUPPORT
		if(bcd_sys.ledSupport()) {
			led_fatal_error.led[item_number] = clear;                           // Clear the led to indicate component
			led.setLeds(led_fatal_error);
		}
#endif //CONFIG_LED_IF_SUPPORT
		ESP_ERROR_CHECK(ESP_FAIL);                                              // Fail with stack trace
	} else {
		
		bcd_sys.setDisplaySupport(true);

		// Clear the display to remove artifacts that may be in buffer
		lcd.clear(lcd.bounds());

		// Display a text version of the boot screen
		//
		draw::text(lcd, bootup_title_area, bootup_title, font, 
			lcd_color::steel_blue);
		draw::text(lcd, bootup_msg_area, bootup_led_msg, font, 
			lcd_color::steel_blue);
		if(led_error == LED_OK) {
			draw::text(lcd, bootup_status_area, ok_msg, font, 
				lcd_color::green);
		} else {
			draw::text(lcd, bootup_status_area, fail_msg, font, 
				lcd_color::yellow);
		}
		draw::text(lcd, 
			bootup_msg_area.offset(0,item_number * font.height()), 
			bootup_display_msg, font, lcd_color::steel_blue);
		draw::text(lcd, 
			bootup_status_area.offset(0, item_number * font.height()), 
			ok_msg, font, lcd_color::green);

#ifdef CONFIG_LED_IF_SUPPORT
		// Set the status led of the display to indicate success
		if(bcd_sys.ledSupport()) {
			led.setLed(item_number, ok);
			vTaskDelay(pdMS_TO_TICKS(500));                                 //Let us enjoy the led 500ms
		}
#endif //CONFIG_LED_IF_SUPPORT
		
	}
#endif //CONFIG_DISPLAY_SUPPORT


	// 2. Setup the filesystems 
	//
	// Second we setup the filesystem to enable the boot screen displaying the
	// logo. As we are on it, we fully initilise all filesystems. Delay is not
	// noticable and doing all here is easier to read the code.
	item_number++;

	// NVS
	//
	// Used for WiFi and to store simple configuration parameters. If we cannot
	// initialise NVS due to a version change or absence of free pages, we 
	// erase NVS (efectively setting the badge back to factory default) and try
	// again. If after this NVS initialisation is not successfull, we fail
	// startup.
#ifdef CONFIG_DISPLAY_SUPPORT
	if(bcd_sys.displaySupport()) {
		draw::text(lcd, 
			bootup_msg_area.offset(0,item_number * font.height()), 
			bootup_fs_msg, font, 
			lcd_color::steel_blue);
	}
#endif //CONFIG_DISPLAY_SUPPORT

	esp_err_t err = nvs_flash_init();
	if (err == ESP_ERR_NVS_NO_FREE_PAGES || err == ESP_ERR_NVS_NEW_VERSION_FOUND) {
		ESP_ERROR_CHECK( nvs_flash_erase() );
		err = nvs_flash_init();
	}
	if(err != ESP_OK) {
		ESP_LOGE(TAG_FS, "Could not initialise NVS: %s (%d)", 
			esp_err_to_name(err), err);
#ifdef CONFIG_DISPLAY_SUPPORT
		if(bcd_sys.displaySupport()) {
			draw::text(lcd, 
				bootup_status_area.offset(0, item_number * font.height()),
				fail_msg, 
				font, 
				lcd_color::orange_red); 
		}
#endif //CONFIG_DISPLAY_SUPPORT
#ifdef CONFIG_LED_IF_SUPPORT
		if(bcd_sys.ledSupport()) {
			led_fatal_error.led[item_number] = clear;
			led.setLeds(led_fatal_error);
		}
#endif //CONFIG_LED_IF_SUPPORT
		ESP_ERROR_CHECK(err);                                                   // Fail if we canot mount nvs.
	}

	// SPIFFS
	//
	// Used to store data, such as for example images to display etc...
	esp_vfs_spiffs_conf_t conf = {
		.base_path = "/spiffs",
		.partition_label = NULL,
		.max_files = 5,
		.format_if_mount_failed = false
	};         
	esp_err_t fs_error = esp_vfs_spiffs_register(&conf);
	if (fs_error != ESP_OK) {
		bcd_sys.setSpiffsSupport(false);                                        // Mark spiffs as not available
		switch(fs_error) {
			case ESP_FAIL:
				ESP_LOGE(TAG_FS, "Failed to mount or format filesystem");
				break;

			case ESP_ERR_NOT_FOUND:
				ESP_LOGE(TAG_FS, "Failed to find SPIFFS partition");
				break;

			default:
				ESP_LOGE(TAG_FS, "Failed to initialize SPIFFS (%d)", fs_error);
		}
#ifdef CONFIG_DISPLAY_SUPPORT
		if(bcd_sys.displaySupport()) {
			draw::text(lcd, 
				bootup_status_area.offset(0,item_number * font.height()), 
				fail_msg, font, lcd_color::yellow);
		}  
#endif //CONFIG_DISPLAY_SUPPORT
#ifdef CONFIG_LED_IF_SUPPORT
		if(bcd_sys.ledSupport()) {
			led.setLed(item_number, fail);
			vTaskDelay(pdMS_TO_TICKS(500));                                     //Let us enjoy the led 500ms
		}
#endif //CONFIG_LED_IF_SUPPORT
	} else {
		size_t total = 0, used = 0;
		fs_error = esp_spiffs_info(NULL, &total, &used);
		if (fs_error != ESP_OK) {
			ESP_LOGE(TAG_FS, "Failed to get SPIFFS partition information");
		} else {
			ESP_LOGI(TAG_FS, "Partition size: total: %d, used: %d", 
				total, used);
		}
#ifdef CONFIG_DISPLAY_SUPPORT
		if(bcd_sys.displaySupport()) {
			draw::text(lcd, 
				bootup_status_area.offset(0,item_number * font.height()), 
				ok_msg, font, lcd_color::green);
		}  
#endif //CONFIG_DISPLAY_SUPPORT
#ifdef CONFIG_LED_IF_SUPPORT
		if(bcd_sys.ledSupport()) {
			// Set led to indicate success
			led.setLed(item_number, ok);
			vTaskDelay(pdMS_TO_TICKS(500));                                     //Let us enjoy the led 500ms
		}
#endif //CONFIG_LED_IF_SUPPORT
	}

	// 3. Setup controller (push buttons)
#ifdef CH405LABS_CONTROLLER_SUPPORT
	item_number++;

#ifdef CONFIG_DISPLAY_SUPPORT
	if(bcd_sys.displaySupport()) {
		draw::text(lcd, 
		bootup_msg_area.offset(0,item_number * font.height()), 
		bootup_controller_msg, font, 
		lcd_color::steel_blue);
	}
#endif //CONFIG_DISPLAY_SUPPORT

	controller_err_t controller_error = controller.config(); 
	if(controller_error != CONTROLLER_OK) {
		ESP_LOGE(TAG_CONTROLLER, "Could not configure embedded controller." 
			"Running without support.");
		bcd_sys.setControllerSupport(false);
#ifdef CONFIG_DISPLAY_SUPPORT
		if(bcd_sys.displaySupport()) {
			draw::text(lcd, bootup_status_area, fail_msg, font, 
					lcd_color::yellow);
		}  
#endif //CONFIG_DISPLAY_SUPPORT
#ifdef CONFIG_LED_IF_SUPPORT
		if(bcd_sys.ledSupport()) {
			led.setLed(item_number, fail);
			vTaskDelay(pdMS_TO_TICKS(500));                                     //Let us enjoy the led 500ms
		}
#endif //CONFIG_LED_IF_SUPPORT
	} else {
#ifdef CONFIG_DISPLAY_SUPPORT
		if(bcd_sys.displaySupport()) {
			draw::text(lcd, 
				bootup_status_area.offset(0,item_number * font.height()), 
				ok_msg, font, lcd_color::green);
		}  
#endif //CONFIG_DISPLAY_SUPPORT
#ifdef CONFIG_LED_IF_SUPPORT
		if(bcd_sys.ledSupport()) {
			led.setLed(item_number, ok);
			vTaskDelay(pdMS_TO_TICKS(500));  //Let us enjoy the led 500ms
		}
#endif //CONFIG_LED_IF_SUPPORT
	}
#else //CH405LABS_CONTROLLER_SUPPORT
	bcd_sys.setControllerSupport(false);
#endif //CH405LABS_CONTROLLER_SUPPORT



	// 4. Setup UART and the console
	// 
	// TODO After this, we should check the led scheduler as theoretically 
	// (althoug rather unlikely) from the console task leds could be used.
	item_number++;

#ifdef CONFIG_DISPLAY_SUPPORT
	if(bcd_sys.displaySupport()) {
		draw::text(lcd, 
			bootup_msg_area.offset(0,item_number * font.height()), 
			bootup_uart_msg, font, 
			lcd_color::steel_blue);
	}
#endif //CONFIG_DISPLAY_SUPPORT

	// Try to start the console. If this fails, we retry once again.
	console_err_t console_error = console.start();
	if(console_error != CONSOLE_OK) {
		ESP_LOGE(TAG_CONSOLE, "Console controller in error state (E:0x%x):" 
			"Resetting...", console_error);
		console_error = console.start();
	} 
	if(console_error == CONSOLE_OK) {
		bcd_sys.setConsoleSupport(true);
#ifdef CONFIG_DISPLAY_SUPPORT
		if(bcd_sys.displaySupport()) {
			draw::text(lcd, 
				bootup_status_area.offset(0,item_number * font.height()), 
				ok_msg, font, lcd_color::green);
		}  
#endif //CONFIG_DISPLAY_SUPPORT
#ifdef CONFIG_LED_IF_SUPPORT
		if(bcd_sys.ledSupport()) {
			led.setLed(item_number, ok);
			vTaskDelay(pdMS_TO_TICKS(500));  //Let us enjoy the led 500ms
		}
#endif //CONFIG_LED_IF_SUPPORT
	} else {
		// Something went wrong spawning the console.Disable capability and 
		// indicate error
		ESP_LOGW(TAG_CONSOLE, "Failed to initialise uart.");
		bcd_sys.setConsoleSupport(false);

#ifdef CONFIG_DISPLAY_SUPPORT
		if(bcd_sys.displaySupport()) {
			draw::text(lcd, 
				bootup_status_area.offset(0,item_number * font.height()), 
				fail_msg, font, lcd_color::yellow);
		}  
#endif //CONFIG_DISPLAY_SUPPORT
#ifdef CONFIG_LED_IF_SUPPORT
		if(bcd_sys.ledSupport()) {
			led.setLed(item_number, fail);
			vTaskDelay(pdMS_TO_TICKS(500));  //Let us enjoy the led 500ms
		}
#endif //CONFIG_LED_IF_SUPPORT
	}

	// Start the main event loop
	//
	// We start the main loop here, as all the drivers that need the main loop
	// to not yet be started (or need to be initialised before drivers that 
	// require the event loop not yet being started are done.)
	esp_event_loop_create_default();
	
	// 5. Initialise WiFi (do not yet connect)
	//
	// We prepare the wifi such that it is ready. However, we do not yet connect
	// even if default credentials are provided.
	item_number++;

#ifdef CONFIG_DISPLAY_SUPPORT
	if(bcd_sys.displaySupport()) {
		draw::text(lcd, 
			bootup_msg_area.offset(0,item_number * font.height()), 
			bootup_wifi_msg, font, 
			lcd_color::steel_blue);
	}
#endif //CONFIG_DISPLAY_SUPPORT

	Wifi.setSsid(WIFI_SSID);
	Wifi.setPassword(WIFI_PASS);
	if(Wifi.init() != ESP_OK) {
		ESP_LOGE(TAG_WIFI, "Failed to initialise WiFi");
		bcd_sys.setWifiSupport(false);

#ifdef CONFIG_DISPLAY_SUPPORT
		if(bcd_sys.displaySupport()) {
			draw::text(lcd, 
				bootup_status_area.offset(0,item_number * font.height()), 
				fail_msg, font, lcd_color::yellow);
		}  
#endif //CONFIG_DISPLAY_SUPPORT
#ifdef CONFIG_LED_IF_SUPPORT
		if(bcd_sys.ledSupport()) {
			led.setLed(item_number, fail);
			vTaskDelay(pdMS_TO_TICKS(500));                                     //Let us enjoy the led 500ms
		}
#endif //CONFIG_LED_IF_SUPPORT
	} else {
		// TODO check if leds are occupied / implement locking mechanism. 
		// Console task or main loop might use them (unlikely)
#ifdef CONFIG_DISPLAY_SUPPORT
		if(bcd_sys.displaySupport()) {
			draw::text(lcd, 
				bootup_status_area.offset(0,item_number * font.height()), 
				ok_msg, font, lcd_color::green);
		}  
#endif //CONFIG_DISPLAY_SUPPORT
#ifdef CONFIG_LED_IF_SUPPORT
		if(bcd_sys.ledSupport()) {
			led.setLed(item_number, ok);
			vTaskDelay(pdMS_TO_TICKS(500));  //Let us enjoy the led 500ms
		}
	}
#endif //CONFIG_LED_IF_SUPPORT
	
	// Give the user some time to read boot screen - if present - and status 
	// leds.
	vTaskDelay(pdMS_TO_TICKS(1500));

#ifdef CONFIG_DEBUG_STACK
	/* Inspect our own high water mark on entering the task. */
	uxHighWaterMark = uxTaskGetStackHighWaterMark( NULL );
	ESP_LOGD(TAG_STACK, "Main:setup(): High watermark for stack at end is: %d", uxHighWaterMark);
#endif	
}


/****************************************************************
 * Main
 * 
 * The main application.
 * 
 * TODO:
 *  - Proper error checking
 ****************************************************************/
void app_main(void) {

#ifdef CONFIG_DEBUG_HEAP
	// Initialise heap tracing to make it available for use later.
	ESP_ERROR_CHECK( heap_trace_init_standalone(trace_record, NUM_RECORDS) );
#endif //CONFIG_DEBUG_HEAP

	App.setup();
	App.run();
}

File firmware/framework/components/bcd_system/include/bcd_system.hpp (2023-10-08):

#pragma once

#include "sdkconfig.h"
#include "driver/gpio.h"
#include "esp_system.h"
#include "esp_spiffs.h"
#include "nvs_flash.h"
#include "esp_vfs_dev.h"

#define TAG_DISPLAY CONFIG_TAG_DISPLAY

#ifdef CONFIG_DISPLAY_SUPPORT
#include "gfx.hpp"
#include "st7735_bcd.hpp"
#include "../resources/bcd_default_font.hpp"
#endif // CONFIG_DISPLAY_SUPPORT

#include "ch405labs_esp_controller.hpp"
#include "ch405labs_esp_led.hpp"
#include "ch405labs_esp_wifi.hpp"
#include "ch405labs_esp_console.hpp"

#ifdef CONFIG_DISPLAY_SUPPORT
// Display definitions
#define LCD_WIDTH       CONFIG_LCD_WIDTH  // 128
#define LCD_HEIGHT      CONFIG_LCD_HEIGHT // 160
#define LCD_ROTATION    3
// A note on the SPI bufffer. If buffer is too small (eg. 1/5 of the display
// size - TODO benchmarks needed), then its probably more efficient to disable
// the copy_from (which leads to using batching instead of blt)
#if CONFIG_IDF_TARGET_ESP32S2 || CONFIG_IDF_TARGET_ESP32S3 || CONFIG_IDF_TARGET_ESP32C3
    #define SPI_BUFFER_SIZE      32768UL // As this is also the max transfer size on S3, TODO verify for S2,C3
#elif CONFIG_IDF_TARGET_ESP32
    #define SPI_BUFFER_SIZE      LCD_HEIGHT*LCD_WIDTH*2+8 // ESP32 max size big enough for full display
#endif //CONFIG_IDF_TARGET

#ifdef CONFIG_SPI2_HOST
    #define LCD_HOST    SPI3_HOST
#else 
    #define LCD_HOST    SPI4_HOST
#endif //CONFIG_SPI2_HOST

// TODO fix properly
#if CONFIG_IDF_TARGET_ESP32S2 || CONFIG_IDF_TARGET_ESP32S3 || CONFIG_IDF_TARGET_ESP32C3
#define DMA_CHAN        SPI_DMA_CH_AUTO
#else // CONFIG_IDF_TARGET_ESP32
#define DMA_CHAN        CONFIG_LCD_DMA_CHANNEL
#endif //CONFIG_IDF_TARGET
#define PIN_NUM_MISO    (gpio_num_t)CONFIG_LCD_PIN_MISO 
#define PIN_NUM_MOSI    (gpio_num_t)CONFIG_LCD_PIN_MOSI
#define PIN_NUM_CLK     (gpio_num_t)CONFIG_LCD_PIN_CLK
#define PIN_NUM_CS      (gpio_num_t)CONFIG_LCD_PIN_CS

#define PIN_NUM_DC      (gpio_num_t)CONFIG_LCD_PIN_DC
#define PIN_NUM_RST     (gpio_num_t)CONFIG_LCD_PIN_RST
#define PIN_NUM_BCKL    (gpio_num_t)CONFIG_LCD_PIN_BCKL

// we use the default, modest buffer - it makes things slower but uses less
// memory. it usually works fine at default but you can change it for performance 
// tuning. It's the final parameter: Note that it shouldn't be any bigger than 
// the DMA size
using lcd_type = espidf::st7735<LCD_WIDTH,
                        LCD_HEIGHT,
                        LCD_HOST,
                        PIN_NUM_CS,
                        PIN_NUM_DC,
                        PIN_NUM_RST,
                        PIN_NUM_BCKL,
                        LCD_ROTATION,
                        SPI_BUFFER_SIZE>;

using lcd_color = gfx::color<typename lcd_type::pixel_type>;
#endif //CONFIG_DISPLAY_SUPPORT

/**
 * @brief A structure that represents the capabilities of the cyberdeck.
 * 
 * The structure is initialised by the chosen capabilities in menuconfig. It is
 * up to the user to update the structure representing actual capabilities. This
 * is usually done by initialising each hardware component and system compnent
 * and update the structure.
 */
class bcd_capabilities {
    public:
        bool fs_spiffs = true;

        bool led = 
#ifdef CONFIG_LED_IF_SUPPORT
        true;
#else //CONFIG_LED_IF_SUPPORT
        false;
#endif //CONFIG_LED_IF_SUPPORT

        bool display = 
#ifdef CONFIG_DISPLAY_SUPPORT
            true;
#else  
            false;
#endif // CONFIG_DISPLAY_SUPPORT

        bool wlan = true;
        bool console = true;
        bool controller = 
#ifdef CONFIG_CH405LABS_CONTROLLER_SUPPORT
            true;
#else
            false;
#endif //CONFIG_CH405LABS_CONTROLLER_SUPPORT
};

/**
 * @brief 
 * 
 * TODO
 *  - Introduce getLastError()
 */
class bcd_system {
    public:
        bcd_system() : spi_host(nullptr,
                        LCD_HOST,
                        PIN_NUM_CLK,
                        PIN_NUM_MISO,
                        PIN_NUM_MOSI,
                        GPIO_NUM_NC,
                        GPIO_NUM_NC,
                        SPI_BUFFER_SIZE,
                        DMA_CHAN) {};

        /**
         * @brief Checks if the cyberdeck supports a display
         * 
         * @return true if a display is supported
         * @return false otherwise
         */
        bool displaySupport();
        void setDisplaySupport(bool s);
#ifdef CONFIG_DISPLAY_SUPPORT
        lcd_type &getDisplay();
        espidf::spi_master &getSpiHost();
#endif //CONFIG_DISPLAY_SUPPORT

        bool ledSupport();
        void setLedSupport(bool s);
#ifdef CONFIG_LED_IF_SUPPORT
        ledDriver &getLedDriver();
#endif //CONFIG_LED_IF_SUPPORT

        bool spiffsSupport();
        void setSpiffsSupport(bool s);

        bool controllerSupport();
        void setControllerSupport(bool s);
#ifdef CONFIG_CH405LABS_CONTROLLER_SUPPORT
        controllerDriver &getControllerDriver();
#endif //CONFIG_CH405LABS_CONTROLLER_SUPPORT

        bool consoleSupport();
        void setConsoleSupport(bool s);
        espconsole::consoleController &getConsoleController();

        bool wifiSupport();
        void setWifiSupport(bool s);
        espwifi::wifiController &getWifiController();

    private:
        bcd_capabilities capabilities;
#ifdef CONFIG_DISPLAY_SUPPORT
        espidf::spi_master spi_host;                                            // object creation initialises spi 
        lcd_type lcd;
#endif //CONFIG_DISPLAY_SUPPORT
#ifdef CONFIG_LED_IF_SUPPORT
        ledDriver& led = ledDriver::getInstance();
#endif //CONFIG_LED_IF_SUPPORT
#ifdef CONFIG_CH405LABS_CONTROLLER_SUPPORT
        controllerDriver controller;
#endif //CONFIG_CH405LABS_CONTROLLER_SUPPORT
        espconsole::consoleController& console = 
            espconsole::consoleController::getInstance();
        espwifi::wifiController wifi;
};

extern bcd_system bcd_sys;

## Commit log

2023-08-15 Initial commit to public repo
    [BCD-0o27.kicad_pcb, BCD-0o27.kicad_sch, BCD-0o27.sch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]
2023-09-12 Changed structure of framework to use submodules
2023-09-12 Added missing console commands in main
    [main.cpp]
2023-09-24 Updated submodule ch405_esp_led for framework and example
2023-09-24 Created new system component that allows direct access to system capabilities and drivers
2023-11-19 Added schematic in pdf form
2024-02-13 Dodajemo board klasu da radimo odvojeno
2024-02-13 prepravljen switch u funkciji za rotiranje
2024-02-13 zavrsene sve funkcije za logiku, fali jos ubaciti da se u frame funkciji pozivaju kako treba
2024-02-14 provaljen timer
2024-02-14 napravljena frame funkcija
